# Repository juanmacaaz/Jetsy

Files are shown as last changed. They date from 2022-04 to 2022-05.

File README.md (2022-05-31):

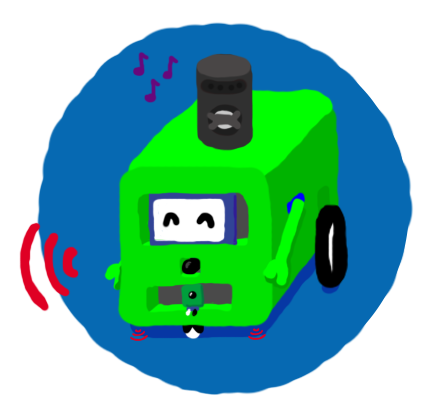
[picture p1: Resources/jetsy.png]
header pic


# Jetsy




Personal assistant robot that interacts with the human being on a physical and emotional level.

# Table of Contents
   * [What is this?](#what-is-this)
   * [Demo](#demo)
   * [Requirements](#requirements)
   * [How to use](#how-to-use)
   * [Components](#components)
   * [Hardware Scheme](#hardware-scheme)
   * [Software Architecture](#software-architecture)
   * [Software Modules](#software-modules)
   * [Eyes](#eyes)
      * [Affirmation](#affirmation)
      * [Loved](#loved)
      * [Suspicious](#suspicious)
      * [Angry](#angry)
      * [Happy](#happy)
      * [Normal](#normal)
      * [Sad](#sad)
   * [Arms](#arms)
   * [Movements](#movements)
      * [Front](#Front)
      * [Left](#Left)
      * [Right](#Right)
      * [Back](#Back)
   * [Proximity Sensors](#proximity-sensors)
   * [Command Voice](#command-voice)
      * [Voice Controller](#voice-controller)
      * [Dance](#dance)
      * [Tell me a joke](#tell-me-a-joke)
      * [Object Classification](#object-classification)
   * [Additional Implementations](#additional-implementations)
   * [Built With](#built-with)
   * [License](#license)
   * [Use-case](#use-case)
   * [Amazing Contribution](#amazing-contribution)
   * [How to contribute](#How-to-contribute)
   * [Citing](#citing)
   * [Support](#support)
   * [Authors](#authors)
   * [Bibliography](#bibliography)

# What is this?
This project seeks to create an autonomous robot completely focused on emotional interaction with the user. It will be carried out by means of a table assistant with already existing typical functionalities, but thanks to artificial intelligence you will be able to interact with it through voice and video and thus enhance robot-human interaction seeking the maximum fluidity possible.

We also believe that the aesthetic design of the robot is very important to be able to transmit emotions to the user, so it will be very well worked.

Another point that we want is that all software has to be open source, from deep learning models to used libraries. You do not need an internet connection to use most of its features.

# Demo
Demo (https://www.youtube.com/watch?v=N_IYzQ1feL4)

# Requirements

For running each sample code:

- [Python 3.9.x](https://www.python.org/)

- [pytorch](https://pytorch.org/)
- [opencv](https://opencv.org/)
- [pipwin](https://pypi.org/project/pipwin/)
- [pyaudio](https://pypi.org/project/PyAudio/)
- [pygame](https://www.pygame.org/)
- [torchaudio](https://pytorch.org/audio/)
- [omegaconf](https://omegaconf.readthedocs.io/)
- [sox](https://pypi.org/project/sox/)
- [noisereduce](https://pypi.org/project/noisereduce/)
- [Levenshtein](https://en.wikipedia.org/wiki/Levenshtein_distance)
- [fuzzywuzzy](https://pypi.org/project/fuzzywuzzy/)

# How to use

1. Clone this repo.

> git clone https://github.com/juanmacaaz/Jetsy

2. Go to the directory where the code is located.

> cd Jesty

3. Install the required libraries.
 
using pip :

> pip install -r Requirements/requirements.txt

4. Execute the following command to run the sample code.

> python3 run.py

5. Add star to this repo if you like it :smiley:. 

# Components
<table align="center" border="0">
<tr>

<td align="center">

[SainSmart Dysplay](https://www.amazon.com/-/es/SainSmart-Display-adaptador-Arduino-2560-Nano/dp/B008FWSG3S)
</td><td align="center">

[Raspberry Pi Camera](https://es.aliexpress.com/item/4001162865845.html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)
</td><td align="center">

[Sg90](https://es.aliexpress.com/item/1005001943420922.html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)
</td><td align="center">

[GA12-N20 DC](https://es.aliexpress.com/item/1005003480074662.html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)
</td></tr>

<tr>
    <td align="center">
        
        
    </td>
    <td align="center">
        
        
    </td>
    <td align="center">
        
        
    </td>
    <td align="center">
        
        
    </td>
</tr>

<tr>

<td align="center">

[infrared barrier module](https://es.aliexpress.com/item/32903218497.html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)
</td><td align="center">

[infrared barrier module](https://es.aliexpress.com/item/1005001621744601.html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)
</td><td align="center">

[L298N](https://www.amazon.es/Neuftech-Puente-conductor-controlador-arduino/dp/B01KBTNHS6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)
</td><td align="center">

[Plastic AA Battery Holder](https://es.aliexpress.com/item/1005001866700713.html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)
</td></tr>

<tr>
    <td align="center">
        
        
    </td>
    <td align="center">
        
        
    </td>
    <td align="center">
        
        
    </td>
    <td align="center">
        
        
    </td>
</tr>

<tr>

<td align="center">

[Arduino Uno](https://es.farnell.com/arduino/k010007/starter-kit-arduino-uno-board/dp/2356913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)
</td><td align="center">

[Power Bank](https://www.amazon.es/Ekrist-26800mAh-Portatil-Powerbank-Cargador/dp/B07TQ43RY2?th=1)
</td><td align="center">

[ALT-37](https://www.carrefour.es/mini-altavoz-innova-wireless-innsoul-alt-37/VC4A-17700772/p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)
</td><td align="center">

[USB Microphone](https://www.amazon.es/Micr%C3%B3fono-Seacue-Omnidireccional-Condensador-Entrevistas/dp/B071171DBP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)
</td></tr>

<tr>
    <td align="center">
        
        
    </td>
    <td align="center">
        
        
    </td>
    <td align="center">
        
        
    </td>
    <td align="center">
        
        
    </td>
</tr>

<tr>

<td align="center">

[Front cover](https://github.com/juanmacaaz/Jetsy/blob/main/HardwareDesign/Models/cuerpo1.stl)
</td><td align="center">

[Back cover](https://github.com/juanmacaaz/Jetsy/blob/main/HardwareDesign/Models/cuerpo2.stl)
</td><td align="center">

[Arms](https://github.com/juanmacaaz/Jetsy/blob/main/HardwareDesign/Models/brazos.stl)
</td><td align="center">

[Battery Cover](https://github.com/juanmacaaz/Jetsy/blob/main/HardwareDesign/Models/tapa.stl)
</td></tr>

<tr>
    <td align="center">
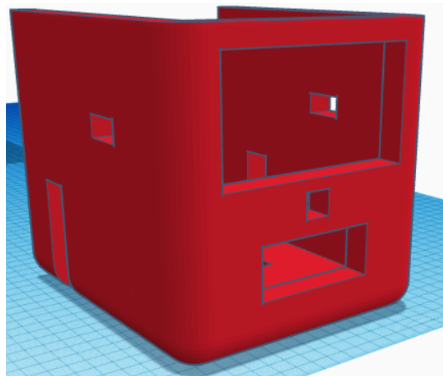
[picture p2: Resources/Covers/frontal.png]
        
        
    </td>
    <td align="center">
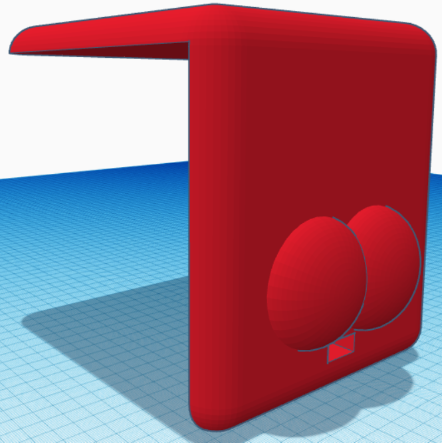
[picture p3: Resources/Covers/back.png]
        
        
    </td>
    <td align="center">
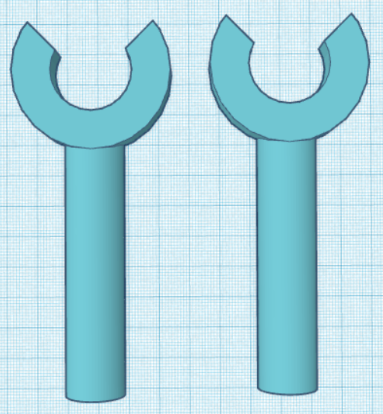
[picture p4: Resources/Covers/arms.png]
        
        
    </td>
    <td align="center">
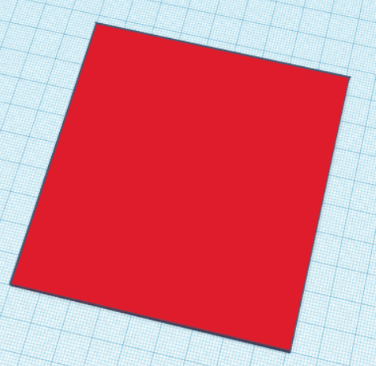
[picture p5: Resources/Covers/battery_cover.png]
        
        
    </td>
</tr>

<tr><td colspan="4">

# Hardware Scheme
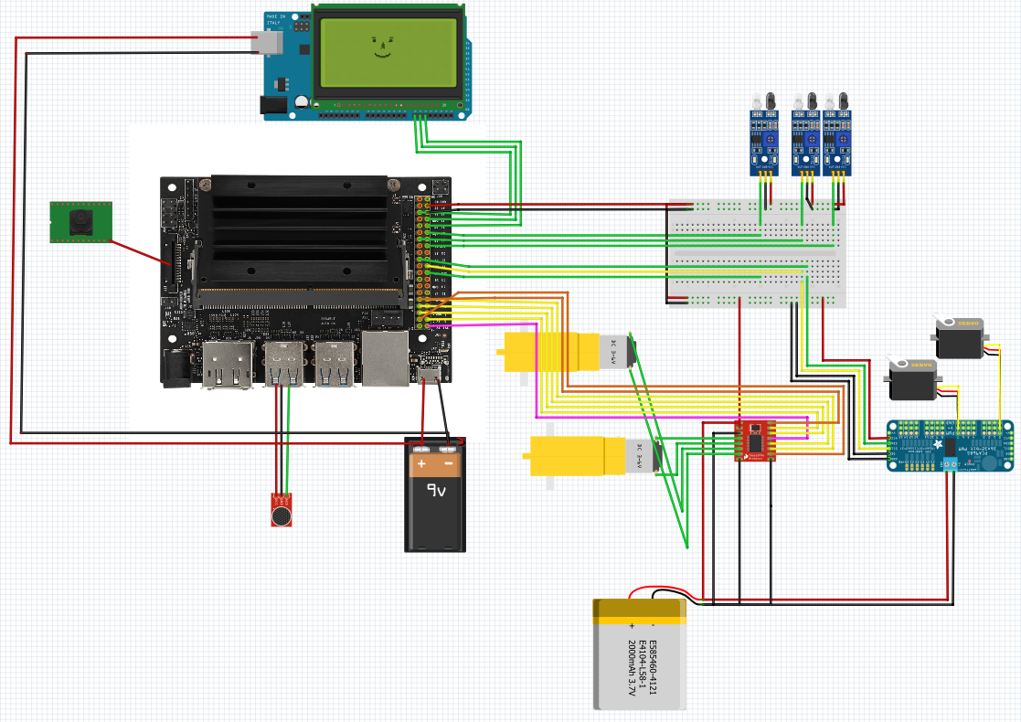
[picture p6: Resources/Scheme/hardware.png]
hardware pic


# Software Architecture
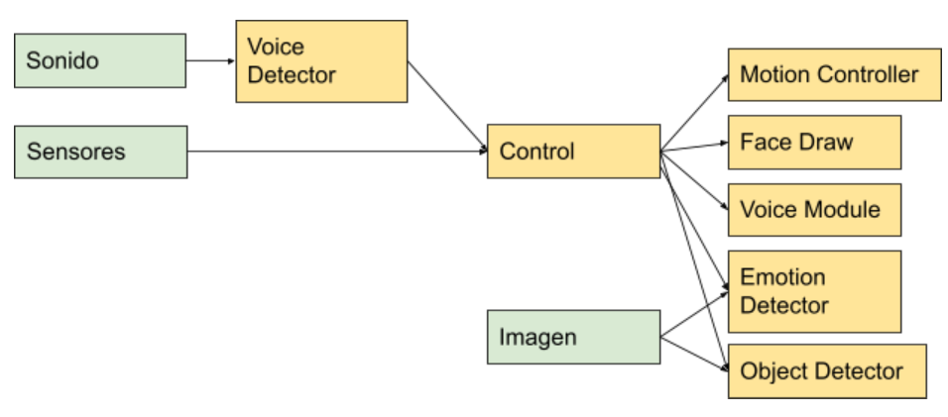
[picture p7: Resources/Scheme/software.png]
software pic


# Software Modules
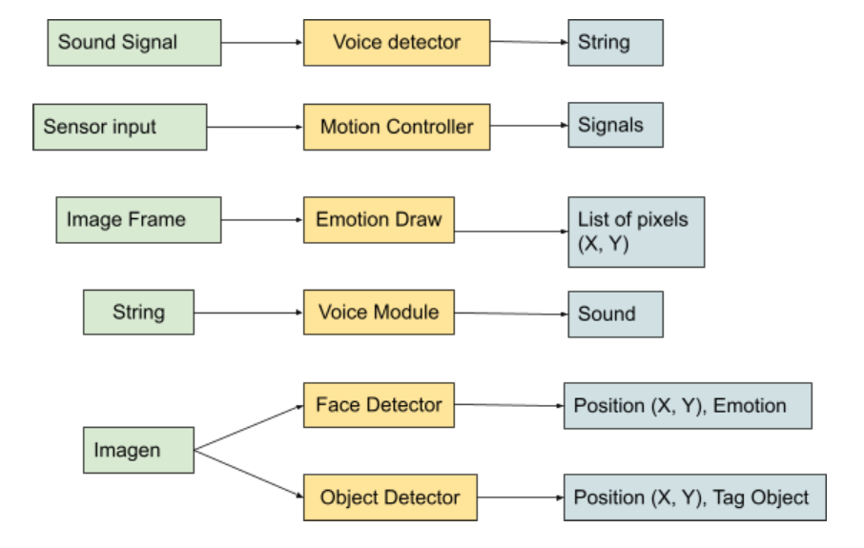
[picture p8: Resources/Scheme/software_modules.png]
software modules pic


# Eyes
## Affirmation
affirmation pic

## Loved
loves pic

## Suspicious
suspicius pic

## Angry
angry pic

## Happy
happy pic

## Normal
normal pic

## Sad
sad pic

# Arms
arm move pic

# Movements
## Front
go pic

## Left
left pic

## Right
right pic

## Back
back pic

# Proximity Sensors
## Frontal
sensor pic

# Command Voice
## Voice Controller
Voice Controller (https://www.youtube.com/watch?v=iem644UcZ8E)

## Dance
Dance (https://www.youtube.com/watch?v=3rkEBKqAFxo)

## Tell me a joke
tell me a joke (https://youtu.be/mcBkq9uVq2E)

## Object Classification
object classification (https://www.youtube.com/watch?v=gnggCI5NF00)

# Additional Implementations
- Where I am
- Emotion Detection
# Built With
- [TinkerCard](https://www.tinkercad.com/) - Model Design Program.
- [Arduino](https://www.arduino.cc/) - IDE used for the development of the servos.
- [VSCode](https://code.visualstudio.com/) - Code editor to program hardware components.
- [Python](https://www.python.org/) - Language used for programming.
- [Adoble Suit](https://www.adobe.com/) - For visual content creation.
# License
This project is under the MIT License - see the [LICENSE](https://github.com/juanmacaaz/Jetsy/blob/main/LICENSE.md) file for details

# Use-Case
If this project helps your robotics project, please let us know with creating an issue.

# Amazing Contribution
- An emotional human-robot interaction never seen before.
- Table assistant 2.0 equipped with artificial intelligence.
- An assistant with next-level computer vision. Leaving current trade assistants behind.
- An easy-to-program framework to add new functionality to the robot.
- All the code is open-source and does not require the internet to work.

# How to contribute
## New estates
In order to create new states you can follow these steps:
1. Adds the initial state of the new functionality in the Default state, this is found in ```state/StateMove.py```.
  
```
  class Default(State):
    next_states = {
        -1: 'Default',
        0: 'Default',
        1: 'InitObject',
        2: 'InitEmotion',
        3: 'InitRepite',
        4: 'InitJoke',
        5: 'InitWhereAmI'
        6: 'Ejemplo1'
    }

    def run(self, kwargs):
        #self.state_machine.global_data['audio'] = None
        audio_state = self.state_machine.global_data['audio']
        kwargs = {}
        self.go_to(self.next_states[audio_state], kwargs)
```
  
2. Create a new voice instruction in ```VoiceDetector/StringMaching.py``` inside list FRASES.
  
```
 FRASES = [
    ("hola detecta objeto", 1),
    ...
    ("hola, esto es un ejemplo", 6)
  ]
```
  
Note: that the second value of the tuple corresponds to the identifier of the new state created in step 1.
  
3. You can now create the different states necessary to carry out the new functionality:
  
```
class Ejemplo1(State):
    def run(self, kwargs):
        kwargs = {}
        kwargs['variable'] = ‘Vengo del estado uno’
        print(f"Inicializando sequencia de test")
        self.go_to("Ejemplo2", kwargs)

class Ejemplo2(State):
    def run(self, kwargs):
        kwargs = {}
        print(f’Mostramos variable {kwargs['variable']}’)
        print(‘Modificamos variable y creamos otra’)
        kwargs['variable']  = ‘He pasado por el estado 2’
        kwargs['variable2'] = ‘He sido creado por el estado 2’
        print(f"Volvemos al estado 1")
        self.go_to("Ejemplo1", kwargs)
 ```
  
**Any contribution is welcome!!**

Contact us via [email](mailto:juanma.caaz@gmail.com).
# Citing
If you use this project's code for your academic work or in industry, we'd love to hear from you as well; feel free to reach out to the developers directly.
# Support 
- [Escola d'Enginyeria - UAB Barcelona](https://www.uab.cat/enginyeria/)
- [UAB Open Labs](https://www.uab.cat/open-labs/)
# Authors
* **Juan Manuel Camara** - [juanmacaaz](https://github.com/juanmacaaz)
* **Miguel del Arco** - [migueldemollet](https://github.com/migueldemollet)
* **Daniel Suarez** - [Danny-8](https://github.com/Danny-8)
* **Christian Ferre** - [christian-ferre](https://github.com/christian-ferre)

# Bibliography
- [Controlar un servo con arduino, Luis Llamas, 2016](https://www.luisllamas.es/controlar-un-servo-con-arduino/)
- [Modulo sensor de llama, Andrés Cortés, 2021](https://acortes.co/proyecto-14-modulo-sensor-de-llama/)
- [Tutorial de uso del modulo l298n, Naylamp Mechatronics, 2017](https://naylampmechatronics.com/blog/11_tutorial-de-uso-del-modulo-l298n.html)
- [CSI Camera, Jetson Hacks Nano, 2019](https://github.com/JetsonHacksNano/CSI-Camera)

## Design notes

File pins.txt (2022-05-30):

dc motors
ENA = 33
ENB = 11
IN1 = 35
IN2 = 37
IN3 = 31
IN4 = 29
----------------------
servos
sda = 3
scl = 5
---------------------
sensor
left = 13
right = 15
frontal = 16
--------------------
pantalla
pin1 = 32
pin2 = 38
pin3 = 40

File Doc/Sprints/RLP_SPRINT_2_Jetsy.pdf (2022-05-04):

RPL - Computer Engineering. UAB (Barcelona) 2020-2021

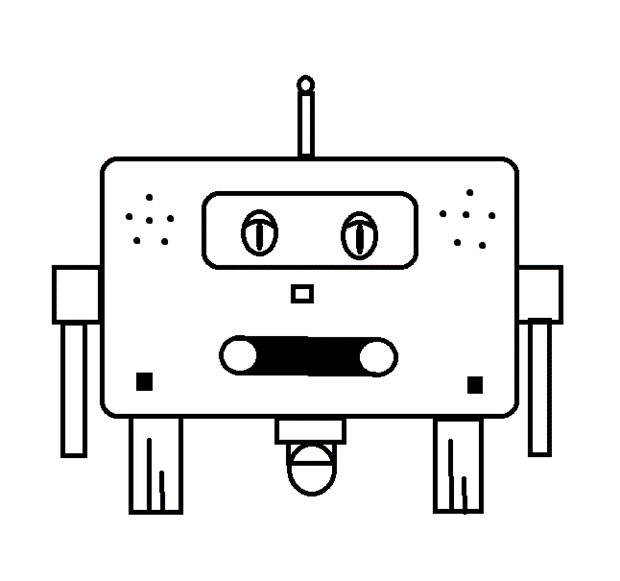
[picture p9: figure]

# JETSY

Robot asistente personal que interactúa con el ser humano a nivel físico y emocional.

PROJECT SPRINT #2.
DATE: 14

th April 2021

Juan Manuel Camara Diaz 1566532 Miguel del Arco Marquez 1566698 Daniel Suárez Valverde 1566103 Christian Ferré Delgado 1565129

JETSY

# Table of Contents

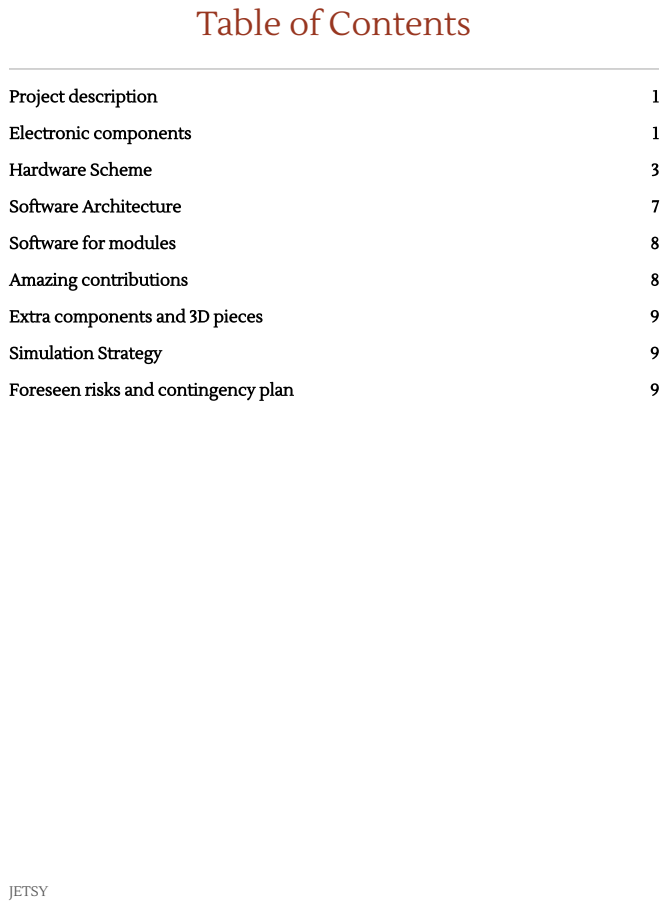
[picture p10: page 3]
Project description; Electronic components; Hardware Scheme; Software Architecture; Software for modules; Amazing contributions; Extra components and 3D pieces; Simulation Strategy; Foreseen risks and contingency plan; JETSY

Sprint #1
Date: 14 April 2021

# JETSY

Robot asistente personal que interactúa con el ser humano a nivel físico y emocional.

Project description
Este proyecto busca crear un robot autónomo completamente enfocado a una interacción emocional con el usuario. Se llevará a cabo mediante un asistente de mesa con funcionalidades típicas ya existentes pero gracias a la inteligencia artificial podrá interactuar con él mediante la voz y video y así potenciar la interacción robot-humano buscando la máxima fluidez posible.

También creemos que el diseño estético del robot es muy importante para poder transmitir emociones al usuario por lo que estará muy trabajado.

Otro punto que queremos es que todo el software tenga que ser open source, desde los modelos de deep learning hasta las librerías usadas. No necesita conexión a internet para poder utilizar la mayoría de sus funcionalidades.

Electronic components
This is the list of the used components:
- Micro servo miniatura SG90 x 3
- Kit motores Dagu 140RPM (2 unidades)
- Controlador de motores TB6612FNG
- Amplificador de audio I2S MAX98357A (3W)
- Batería Lipo 3500mAh 2S 25C, 7.4V
JETSY | 1

- Arducam 5MP 1080p OV5647 RASPBERRY PI
- Altavoz con caja - 3W
- tft_320qvt_9341
- Micrófono electret preamplificado
- Power Bank 5000 MAh, 1x USB-A
- Raspberry Pi 3 Modelo A+ (Jetson Nano)
- INMSDH32G-100V10
- SENSOR INFRARROJO DE LLAMA x 2
- Controlador de Servos PCA9685
JETSY | 2

Hardware Scheme
Diagrama del Hardware

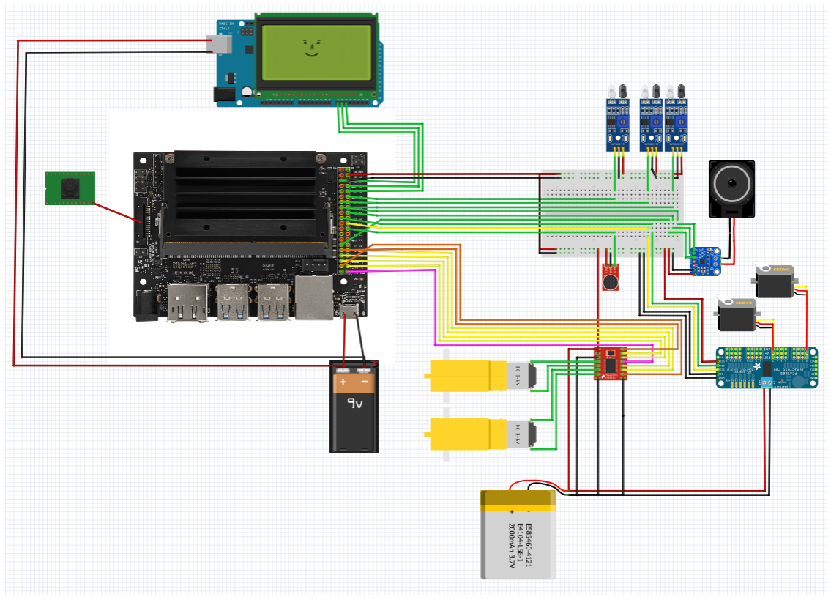
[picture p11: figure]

- Controlador de Servos PCA9685
- GND -> GND(38)
- OE -> GND(38)
- SCL -> PinOut(10)
- SDA -> PinOut(32)
- VCC -> 5V (39)
JETSY | 3

- Micro servo miniatura SG90 x2
- VCC -> V+(0,7) (Controlador de Servos PCA9685)
- GND -> GND(0,7) (Controlador de Servos PCA9685)
- Pulse -> PWM (0,7) (Controlador de Servos PCA9685)
- Kit motores Dagu 140RPM x2
- Pin1 -> A01/B02 (Controlador de motores TB6612FNG)
- Pin1 -> A02/B01 (Controlador de motores TB6612FNG)
- Controlador de motores TB6612FNG
- VM -> + (Batería Lipo 3500mAh 2S 25C, 7.4V)
- VCC -> 5V (39)
- GND -> - (Batería Lipo 3500mAh 2S 25C, 7.4V)
- PWMA -> PinOut(16)
- AIN2 -> PinOut(22)
- AIN1 -> PinOut(18)
- STBY -> PinOut(21)
- BIN1 -> PinOut(17)
- BIN2 -> PinOut(25)
- PWMB -> PinOut(19)
- Amplificador de audio I2S MAX98357A (3W)
- VIN -> 5V (39)
JETSY | 4

- GND -> GND(38)
- DIN -> PinOut(15)
- BCLK -> PinOut(28)
- LRC -> PinOut(8)
- Batería Lipo 3500mAh 2S 25C, 7.4V
- Arducam 5MP 1080p OV5647 RASPBERRY PI
- Conexion camara Jetson
- Altavoz con caja - 3W
- + -> + (Amplificador de audio I2S MAX98357A (3W))
- - -> - (Amplificador de audio I2S MAX98357A (3W))
- tft_320qvt_9341
- Conectada directamente al arduino con el adaptador
- Micrófono electret preamplificado
- VCC -> 5V (39)
- GND -> GND(38)
- AUD -> PinOut(29)
- Power Bank 5000 MAh, 1x USB-A
- Micro USB Jetson
- Raspberry Pi 3 Modelo A+ (Jetson Nano)
- INMSDH32G-100V10
JETSY | 5

- SD socket
- SENSOR INFRARROJO DE LLAMA x3
- VCC -> 5V (39)
- GND -> GND(38)
- OUT -> PinOut(7, 33, 35)
JETSY | 6

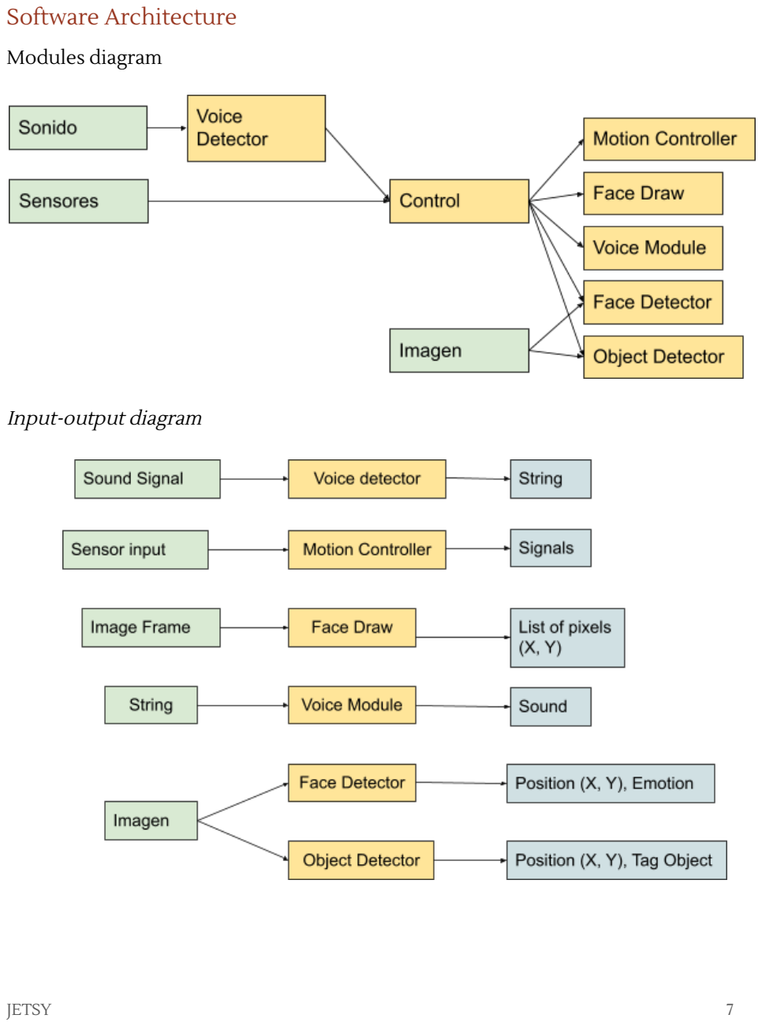
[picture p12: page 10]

Software Architecture
Modules diagram

Input-output diagram

JETSY | 7

Software modules
Para los diferentes módulos vamos a usar el siguiente software:

Voice Detector: Utiliza un modelo pre-entrenado de reconocimiento de voz, los comandos de voz serán en inglés. El modelo es: https://github.com/snakers4/silero-models

Monitor Controller: Máquina de estados del robot y quien comunica todos los

Face Draw: Es una máquina de estado de animaciones implementada en el arduino mega. Los estados serán controlados por los pines de input. Para poder almacenar las animaciones de los ojos hemos tenido que crear un script para poder comprimirlas. La compresión se basa en solo almacenar aquellos píxeles que son modificados respecto al frame anterior. Gracias a esto conseguimos comprimir hasta 800 veces de promedio las animaciones. También conseguimos que la animación se vea super fluida aun teniendo una pantalla con una tasa de refresco muy limitada.

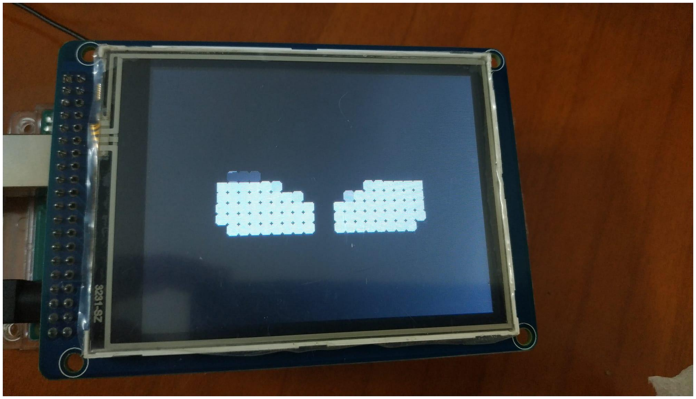
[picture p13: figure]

Las animaciones comprimidas tienen el siguiente formato (Cada campo es un byte):

[#Frames] [#Cambios frame 0] [#Cambios frame 1] . . . [Cambios frame 0] . . .

Voice Module: Función que recibe un string como input y envía al altavoz la orden para que reproduzca el contenido del string.

La implementación de este módulo ha sido mediante la librería “pyttsx3”. Hemos elegido esta librería ya que es offline y muy eficiente.

JETSY | 8

Face Detector: Función que recibe como input una imagen, ésta es preprocesada para lograr simplificar la información lo máximo posible y, a través de un modelo clasificador devuelve la etiqueta de la emoción que representa la cara.

Utilizará el siguiente modelo de deep learning para detectar la emoción https://github.com/serengil/deepface

Object Detector: Modelo de deep learning encargado de detectar todo tipo de objetos. Es el siguiente: https://pjreddie.com/darknet/yolo/

Amazing contributions
Una interacción humano-robot emocional nunca vista.

Asistente de mesa 2.0 dotado de inteligencia artificial.

Un asistente con una visión por computador al siguiente nivel. Dejando atrás a los asistentes comerciales actuales.

JETSY | 9

Extra components and 3D pieces
- Cuerpo del robot (carcasas)
- Frontal

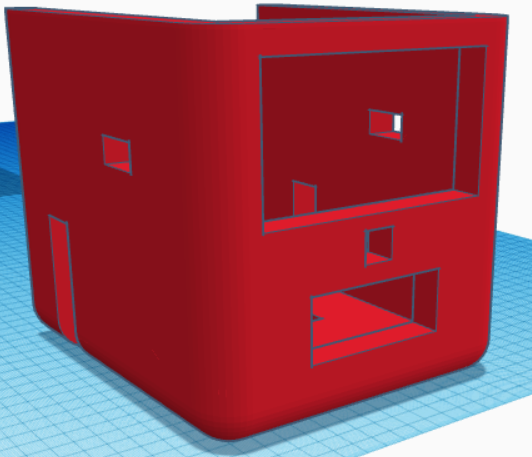
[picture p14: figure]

- Trasero

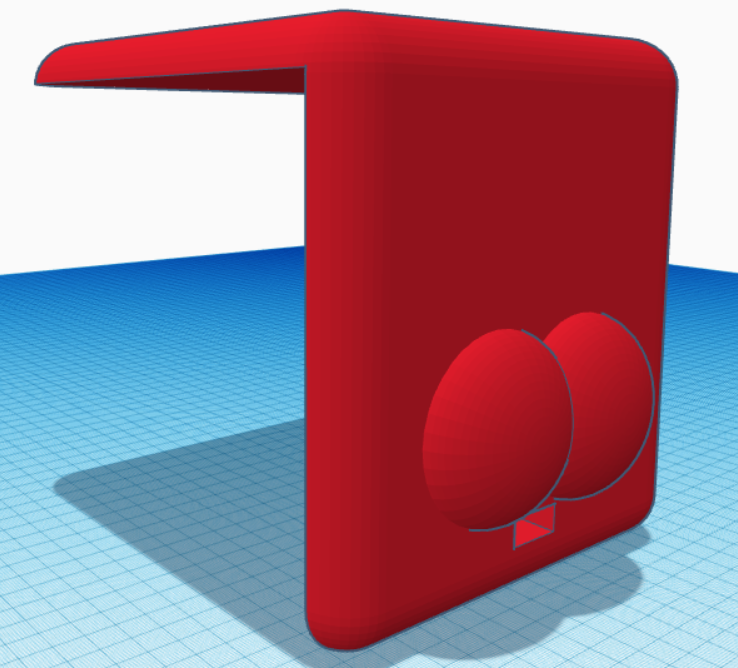
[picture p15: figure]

JETSY | 10

- Brazo x2

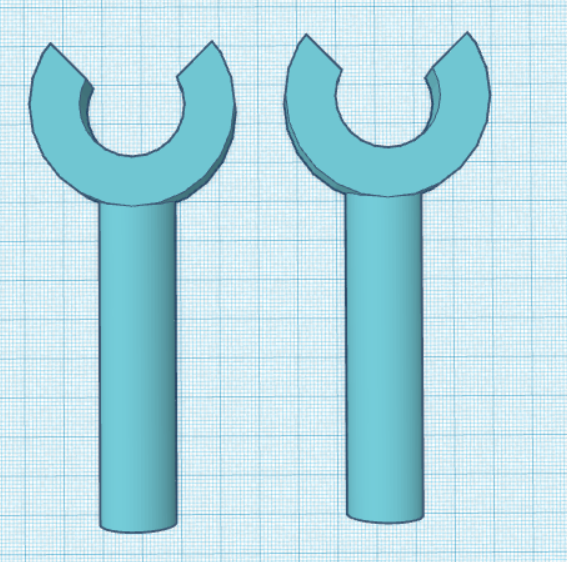
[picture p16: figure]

- Tapa de pilas

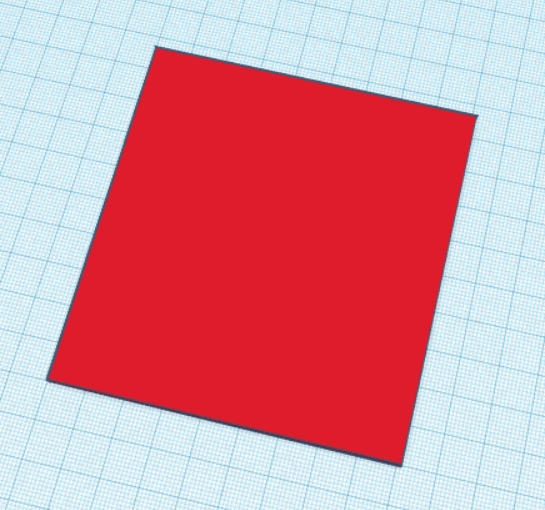
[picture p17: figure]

JETSY | 11

Simulation Strategy
Para llevar a cabo el robot vamos a crear algunos simuladores mientras se realiza la implementación hardware software.

Para simular una pantalla LCD crearemos un simulador con la librería: PyGame

Al obtener las piezas no hemos optado por simular nada hardware. Todo el software para ser testeado será con un ordenador con Ubuntu 20.04, por lo que no necesitaremos ningún tipo de simulador.

Foreseen risks and contingency plan

Risk# | Description | Probability | Impact | Contingency plan
1 | Fallo de Bateria | Low | Low | No usar baterias
2 Bajo rendimiento | de CPU/GPU | Low | Low | Reducir el número de módulos de Deep Learning.
3 Máquina de | estados compleja | Medium | Low | Reducir las funcionalidades del robot
4 Mal | reconocimiento de voz | Low | Medium | Ajustar algunas palabras clave
5 Grandes | interferencias de audio | Low | Medium | Reducir la calidad del sonido para evitar las interferencias o usar una api externa.
6 No hacer un | proyecto open-source | Medium | Low | Usar código y APIs no open-source
7 Que el robot no | se pueda estabilizar bien con las ruedas | Low | Medium | Distribución correcta del peso
JETSY | 12

### 8 Falta de espacio

dentro del robot

Low | Medium | Hacer un buen diseño 3D de las piezas o hacerlo manual
JETSY | 13

# References

This project has been inspired by the following Internet projects:

- https://living.ai/emo/
- https://developer.amazon.com/es-ES/alexa
- https://www.digitaldreamlabs.com/pages/cozmo

Other links

- https://www.youtube.com/watch?v=8QD6HqL9Qc0&t=7s
- https://pjreddie.com/darknet/yolo/
- https://github.com/snakers4/silero-models
- https://github.com/serengil/deepface
JETSY | 14

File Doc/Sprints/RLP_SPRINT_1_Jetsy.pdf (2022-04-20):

RPL - Computer Engineering. UAB (Barcelona) 2020-2021


# JETSY

Robot asistente personal que interactúa con el ser humano a nivel físico y emocional.

PROJECT SPRINT #0.
DATE: 14

th April 2021

Juan Manuel Camara Diaz 1566532 Miguel del Arco Marquez 1566698 Daniel Suárez Valverde 1566103 Christian Ferré Delgado 1565129

JETSY

# Table of Contents

Project description; Electronic components; Hardware Scheme; Software Architecture; Software for modules; Amazing contributions; Extra components and 3D pieces; Simulation Strategy; Foreseen risks and contingency plan; JETSY

Sprint #1
Date: 14 April 2021

# JETSY

Robot asistente personal que interactúa con el ser humano a nivel físico y emocional.

Project description
Este proyecto busca crear un robot autónomo completamente enfocado a una interacción emocional con el usuario. Se llevará a cabo mediante un asistente de mesa con funcionalidades típicas ya existentes pero gracias a la inteligencia artificial podrá interactuar con él mediante la voz y video y así potenciar la interacción robot-humano buscando la máxima fluidez posible.

También creemos que el diseño estético del robot es muy importante para poder transmitir emociones al usuario por lo que estará muy trabajado.

Otro punto que queremos es que todo el software tenga que ser open source, desde los modelos de deep learning hasta las librerías usadas. No necesita conexión a internet para poder utilizar la mayoría de sus funcionalidades.

Electronic components
This is the list of the used components:
- Sensor de distancia por ultrasonidos
- Micro servo miniatura SG90 x 3
- Kit motores Dagu 140RPM (2 unidades)
- Controlador de motores TB6612FNG
- Amplificador de audio I2S MAX98357A (3W)
JETSY | 1

- Batería Lipo 3500mAh 2S 25C, 7.4V
- Arducam 5MP 1080p OV5647 RASPBERRY PI
- Altavoz con caja - 3W
- tft_320qvt_9341
- Micrófono electret preamplificado
- Power Bank 5000 MAh, 1x USB-A
- Raspberry Pi 3 Modelo A+ (Jetson Nano)
- INMSDH32G-100V10
- SENSOR INFRARROJO DE LLAMA x 2
JETSY | 2

Hardware Scheme
Diagrama del Hardware

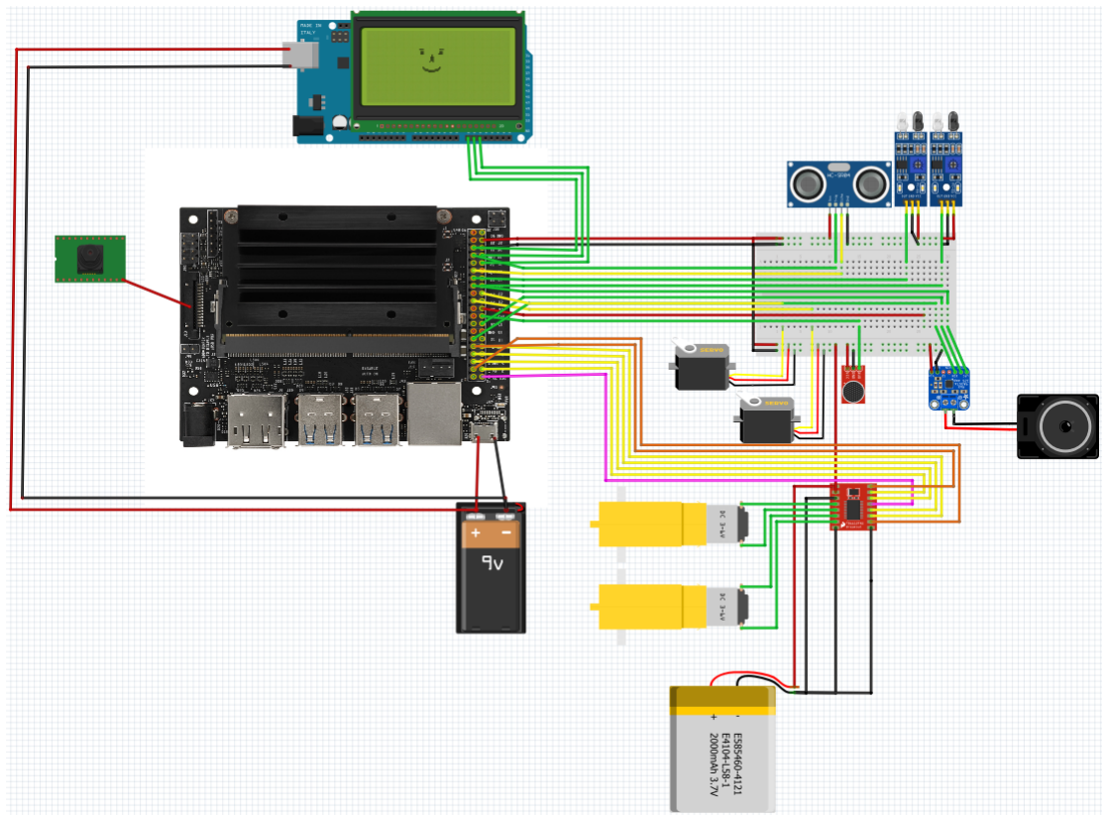
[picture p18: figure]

- Sensor de distancia por ultrasonidos
- VCC -> 5V(39)
- GND -> GND(38)
- Trig -> PinOut(4)
- Echo -> PinOut(6)
JETSY | 3

- Micro servo miniatura SG90
- VCC -> 5V (39)
- GND -> GND(38)
- Pulse -> PinOut(10)
- Micro servo miniatura SG90
- VCC -> 5V (39)
- GND -> GND(38)
- Pulse -> PinOut(32)
- Kit motores Dagu 140RPM
- Pin1 -> A01 (Controlador de motores TB6612FNG)
- Pin1 -> A02 (Controlador de motores TB6612FNG)
- Kit motores Dagu 140RPM
- Pin1 -> B02 (Controlador de motores TB6612FNG)
- Pin1 -> B01 (Controlador de motores TB6612FNG)
- Controlador de motores TB6612FNG
- VM -> + (Batería Lipo 3500mAh 2S 25C, 7.4V)
- VCC -> 5V (39)
- GND -> - (Batería Lipo 3500mAh 2S 25C, 7.4V)
- PWMA -> PinOut(16)
- AIN2 -> PinOut(22)
JETSY | 4

- AIN1 -> PinOut(18)
- STBY -> PinOut(21)
- BIN1 -> PinOut(17)
- BIN2 -> PinOut(25)
- PWMB -> PinOut(19)
- Amplificador de audio I2S MAX98357A (3W)
- VIN -> 5V (39)
- GND -> GND(38)
- DIN -> PinOut(15)
- BCLK -> PinOut(28)
- LRC -> PinOut(8)
- Batería Lipo 3500mAh 2S 25C, 7.4V
- Arducam 5MP 1080p OV5647 RASPBERRY PI
- Conexion camara Jetson
- Altavoz con caja - 3W
- + -> + (Amplificador de audio I2S MAX98357A (3W))
- - -> - (Amplificador de audio I2S MAX98357A (3W))
- tft_320qvt_9341
- Conectada directamente al arduino con el adaptador
- Micrófono electret preamplificado
JETSY | 5

- VCC -> 5V (39)
- GND -> GND(38)
- AUD -> PinOut(29)
- Power Bank 5000 MAh, 1x USB-A
- Micro USB Jetson
- Raspberry Pi 3 Modelo A+ (Jetson Nano)
- INMSDH32G-100V10
- SD socket
- SENSOR INFRARROJO DE LLAMA
- VCC -> 5V (39)
- GND -> GND(38)
- OUT -> PinOut(7)
- SENSOR INFRARROJO DE LLAMA
- VCC -> 5V (39)
- GND -> GND(38)
- OUT -> PinOut(33)
JETSY | 6

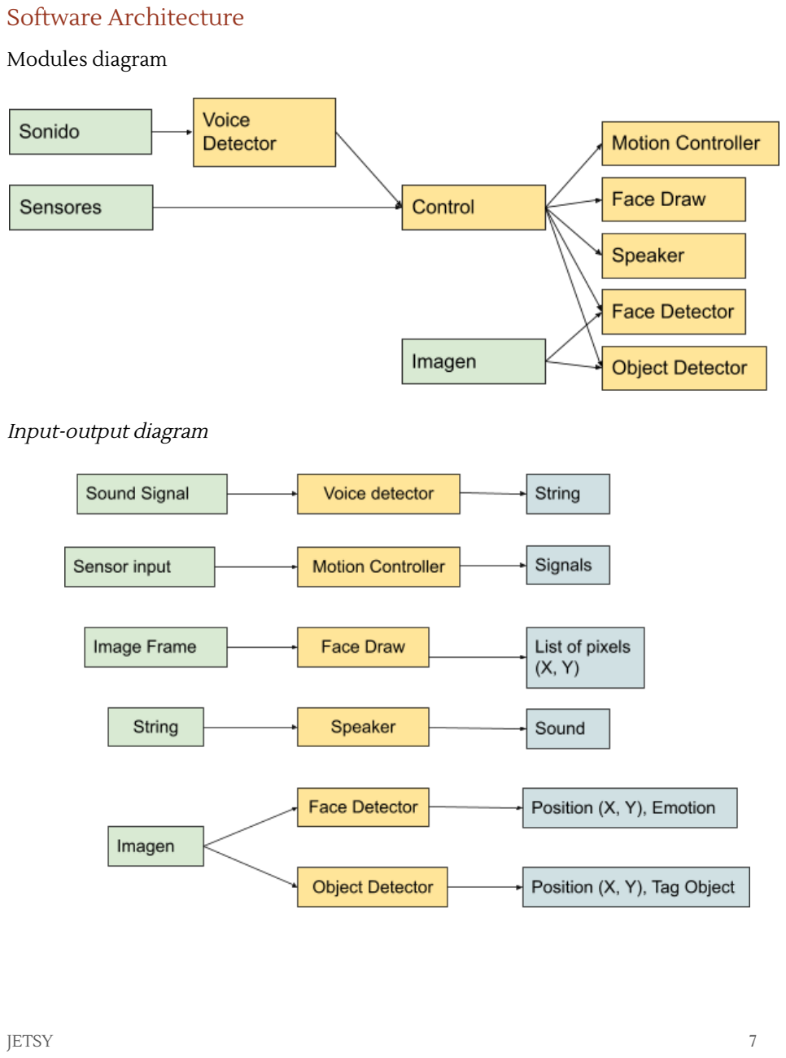
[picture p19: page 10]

Software Architecture
Modules diagram

Input-output diagram

JETSY | 7

Software for modules
Para los diferentes módulos vamos a usar el siguiente software:

Voice Detector: Utiliza un modelo pre-entrenado de reconocimiento de voz, los comandos de voz serán en inglés. El modelo es: https://github.com/snakers4/silero-models

Monitor Controller: Máquina de estados del robot y quien comunica todos los

Face Draw: Es una máquina de estado de animaciones implementada en el arduino mega. Los estados serán controlados por los pines de input.

Speaker: Función que recibe un string como input y envía al altavoz la orden para que reproduzca el contenido del string.

Face Detector: Función que recibe como input una imagen, ésta es preprocesada para lograr simplificar la información lo máximo posible y, a través de un modelo clasificador devuelve la etiqueta de la emoción que representa la cara.

Utilizará el siguiente modelo de deep learning para detectar la emoción https://github.com/serengil/deepface

Object Detector: Modelo de deep learning encargado de detectar todo tipo de objetos. Es el siguiente: https://pjreddie.com/darknet/yolo/

Amazing contributions
Una interacción humano-robot emocional nunca vista.

Asistente de mesa 2.0 dotado de inteligencia artificial.

Un asistente con una visión por computador al siguiente nivel. Dejando atrás a los asistentes comerciales actuales.

JETSY | 8

Extra components and 3D pieces
- Cuerpo del robot (carcasas)
- Frontal


- Trasero


JETSY | 9

- Brazo x2


- Tapa de pilas


JETSY | 10

Simulation Strategy
Para llevar a cabo el robot vamos a crear algunos simuladores mientras se realiza la implementación hardware software.

Para simular una pantalla LCD crearemos un simulador con la librería: PyGame

Al obtener las piezas no hemos optado por simular nada hardware. Todo el software para ser testeado será con un ordenador con Ubuntu 20.04, por lo que no necesitaremos ningún tipo de simulador.

Foreseen risks and contingency plan

Risk# | Description | Probability | Impact | Contingency plan
1 | Fallo de Bateria | Low | Low | No usar baterias
2 Bajo rendimiento | de CPU/GPU | Low | Low | Reducir el número de módulos de Deep Learning.
3 Máquina de | estados compleja | Medium | Low | Reducir las funcionalidades del robot
4 Mal | reconocimiento de voz | Low | Medium | Ajustar algunas palabras clave
5 Grandes | interferencias de audio | Low | Medium | Reducir la calidad del sonido para evitar las interferencias o usar una api externa.
6 No hacer un | proyecto open-source | Medium | Low | Usar código y APIs no open-source
7 Que el robot no | se pueda estabilizar bien con las ruedas | Low | Medium | Distribución correcta del peso
JETSY | 11

### 8 Falta de espacio

dentro del robot

Low | Medium | Hacer un buen diseño 3D de las piezas o hacerlo manual
JETSY | 12

# References

This project has been inspired by the following Internet projects:

- https://living.ai/emo/
- https://developer.amazon.com/es-ES/alexa
- https://www.digitaldreamlabs.com/pages/cozmo

Other links

- https://www.youtube.com/watch?v=8QD6HqL9Qc0&t=7s
- https://pjreddie.com/darknet/yolo/
- https://github.com/snakers4/silero-models
- https://github.com/serengil/deepface
JETSY | 13

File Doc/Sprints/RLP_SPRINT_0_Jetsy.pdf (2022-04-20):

RPL - Computer Engineering. UAB (Barcelona) 2020-2021


# JETSY

Robot asistente personal que interactúa con el ser humano a nivel físico y emocional.

PROJECT SPRINT #0.
DATE: 14

th April 2021

Juan Manuel Camara Diaz 1566532 Miguel del Arco Marquez 1566698 Daniel Suárez Valverde 1566103 Christian Ferré Delgado 1565129

JETSY

# Table of Contents

Project description | 1
Electronic components | 1
Scheme | 1
Extra components and 3D pieces | 1
Foreseen risks and contingency plan | 2

JETSY

Sprint #0
Date: 14 April 2021

# JETSY

Robot asistente personal que interactúa con el ser humano a nivel físico y emocional.

Project description
Este proyecto busca crear un robot autónomo completamente enfocado a una interacción emocional con el usuario. Se llevará a cabo mediante un asistente de mesa con funcionalidades típicas ya existentes pero gracias a la inteligencia artificial podrá interactuar con él mediante la voz y video y así potenciar la interacción robot-humano buscando la máxima fluidez posible.

También creemos que el diseño estético del robot es muy importante para poder transmitir emociones al usuario por lo que estará muy trabajado.

Otro punto que queremos es que todo el software tenga que ser open source, desde los modelos de deep learning hasta las librerías usadas.

Electronic components
This is the list of the used components:
- Sensor de distancia por ultrasonidos
- Micro servo miniatura SG90 x 3
- Kit motores Dagu 140RPM (2 unidades)
- Controlador de motores TB6612FNG
- Amplificador de audio I2S MAX98357A (3W)
- Batería Lipo 3500mAh 2S 25C, 7.4V
JETSY | 1

- Arducam 5MP 1080p OV5647 RASPBERRY PI
- Altavoz con caja - 3W
- PANTALLA 1.8" LCD/TFT
- Micrófono electret preamplificado
- Power Bank 5000 MAh, 1x USB-A
- Raspberry Pi 3 Modelo A+ (Jetson Nano)
- INMSDH32G-100V10
- SENSOR INFRARROJO DE LLAMA x 2
JETSY | 2

Hardware Scheme
Diagrama del Hardware

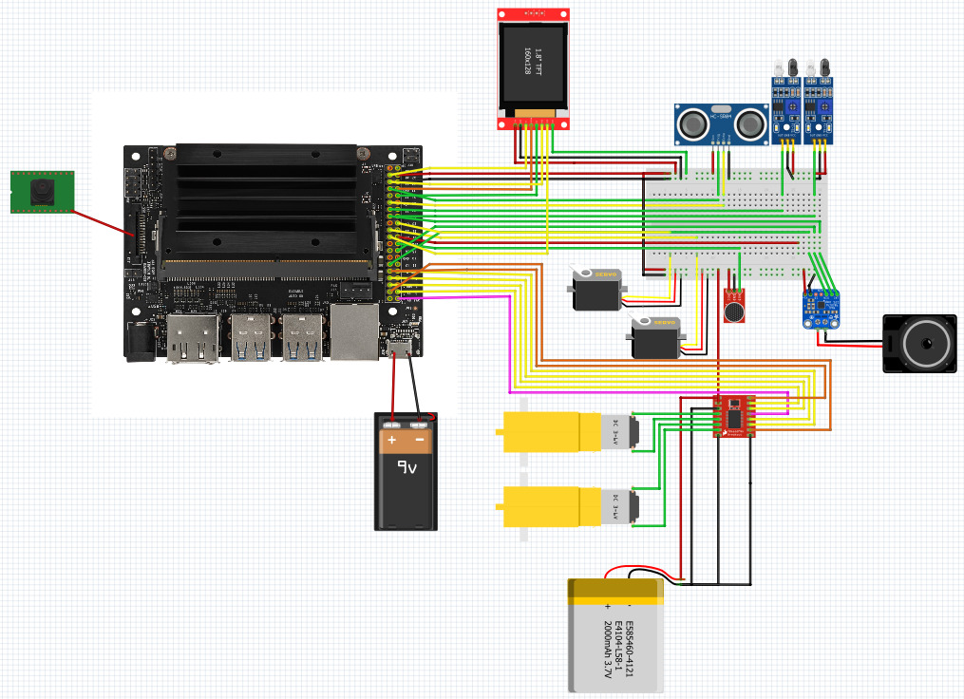
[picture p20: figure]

- Sensor de distancia por ultrasonidos
- VCC -> 5V(39)
- GND -> GND(38)
- Trig -> PinOut(4)
- Echo -> PinOut(6)
JETSY | 3

- Micro servo miniatura SG90
- VCC -> 5V (39)
- GND -> GND(38)
- Pulse -> PinOut(10)
- Micro servo miniatura SG90
- VCC -> 5V (39)
- GND -> GND(38)
- Pulse -> PinOut(32)
- Kit motores Dagu 140RPM
- Pin1 -> A01 (Controlador de motores TB6612FNG)
- Pin1 -> A02 (Controlador de motores TB6612FNG)
- Kit motores Dagu 140RPM
- Pin1 -> B02 (Controlador de motores TB6612FNG)
- Pin1 -> B01 (Controlador de motores TB6612FNG)
- Controlador de motores TB6612FNG
- VM -> + (Batería Lipo 3500mAh 2S 25C, 7.4V)
- VCC -> 5V (39)
- GND -> - (Batería Lipo 3500mAh 2S 25C, 7.4V)
- PWMA -> PinOut(16)
- AIN2 -> PinOut(22)
JETSY | 4

- AIN1 -> PinOut(18)
- STBY -> PinOut(21)
- BIN1 -> PinOut(17)
- BIN2 -> PinOut(25)
- PWMB -> PinOut(19)
- Amplificador de audio I2S MAX98357A (3W)
- VIN -> 5V (39)
- GND -> GND(38)
- DIN -> PinOut(15)
- BCLK -> PinOut(28)
- LRC -> PinOut(8)
- Batería Lipo 3500mAh 2S 25C, 7.4V
- Arducam 5MP 1080p OV5647 RASPBERRY PI
- Conexion camara Jetson
- Altavoz con caja - 3W
- + -> + (Amplificador de audio I2S MAX98357A (3W))
- - -> - (Amplificador de audio I2S MAX98357A (3W))
- PANTALLA 1.8" LCD/TFT
- VCC -> 5V(39)
- GND -> GND(38)
JETSY | 5

- CS -> PinOut(2)
- RESET -> PinOut(37)
- A0 -> PinOut(36)
- SDA -> PinOut(3)
- SCK -> PinOut(11)
- LED -> 5V (39)
- Micrófono electret preamplificado
- VCC -> 5V (39)
- GND -> GND(38)
- AUD -> PinOut(29)
- Power Bank 5000 MAh, 1x USB-A
- Micro USB Jetson
- Raspberry Pi 3 Modelo A+ (Jetson Nano)
- INMSDH32G-100V10
- SD socket
- SENSOR INFRARROJO DE LLAMA
- VCC -> 5V (39)
- GND -> GND(38)
- OUT -> PinOut(7)
- SENSOR INFRARROJO DE LLAMA
JETSY | 6

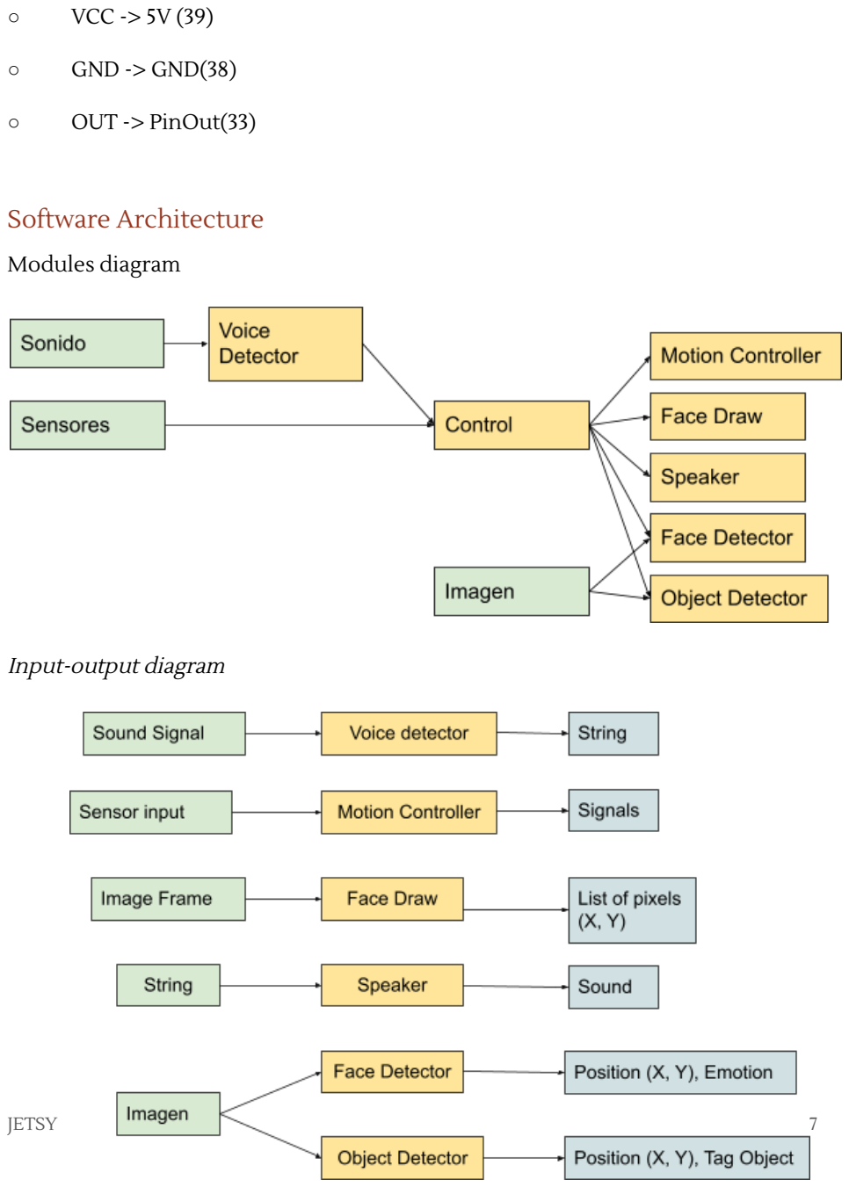
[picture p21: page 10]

- VCC -> 5V (39)
- GND -> GND(38)
- OUT -> PinOut(33)

Software Architecture
Modules diagram

Input-output diagram

JETSY | 7

Amazing contributions
Una interacción humano-robot emocional nunca vista.

Asistente de mesa 2.0

Extra components and 3D pieces
- Cuerpo del robot (carcasas)
- Rueda x2
- Brazo x2
- Rueda loca x1
- Tapa enchufe x1

Simulation Strategy
Para llevar a cabo el robot vamos a crear algunos simuladores mientras se reliza la implmentacion hardware sofrware.

Para simular una pantalla LCD crearemos un simulador.

PyGame

FaceDraw

JETSY | 8

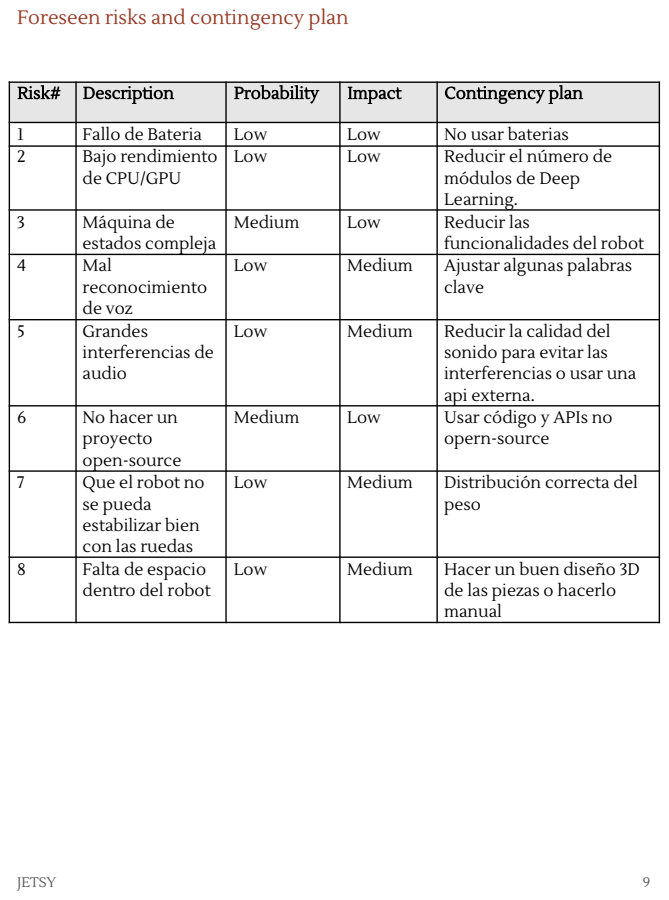
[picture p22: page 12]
JETSY

Foreseen risks and contingency plan

Risk# | Description | Probability | Impact | Contingency plan

1 | Fallo de Bateria | Low | Low | No usar baterias
2 Bajo rendimiento | de CPU/GPU | Low | Low | Reducir el número de módulos de Deep Learning.

3 Máquina de | estados compleja | Medium | Low | Reducir las funcionalidades del robot

4 Mal | reconocimiento de voz | Low | Medium | Ajustar algunas palabras clave

5 Grandes | interferencias de audio | Low | Medium | Reducir la calidad del sonido para evitar las interferencias o usar una api externa.

6 No hacer un | proyecto open-source | Medium | Low | Usar código y APIs no opern-source

7 Que el robot no | se pueda estabilizar bien con las ruedas | Low | Medium | Distribución correcta del peso

8 Falta de espacio | dentro del robot | Low | Medium | Hacer un buen diseño 3D de las piezas o hacerlo manual

# References

This project has been inspired by the following Internet projects:

- https://living.ai/emo/
- https://developer.amazon.com/es-ES/alexa
- https://www.digitaldreamlabs.com/pages/cozmo

Other links

- https://www.youtube.com/watch?v=8QD6HqL9Qc0&t=7s
- https://pjreddie.com/darknet/yolo/
- https://github.com/snakers4/silero-models
JETSY | 10

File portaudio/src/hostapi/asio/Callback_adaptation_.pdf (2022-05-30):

GRAME - Computer Music Research Lab.

### Technical Note - 01-11-07

# Callback adaptation techniques

Stéphane Letz
November 2001
Grame - Computer Music Research Laboratory 9, rue du Garet BP 1185 69202 FR - LYON Cedex 01 letz@grame.fr

Abstract

This document describes a callback adaptation technique developed for the PortAudio port on ASIO. This method handle buffers of different sizes and guarantee lowest latency added by buffer size adaptation.

### 1 Introduction

The callback adaptation problem was encountered whilst doing a port of the PortAudio API on ASIO API. PortAudio is a cross-platform library that provides streaming audio input and output, ASIO is a Macintosh and Windows API that provides streaming audio input and output. Both API are callback based, but may use audio buffers of different size. This document presents an algorithm developed to allow adaptation between the 2 callback systems.

### 2 Adapting callbacks

The system we are considering is driven by an audio native callback (the “host” callback) usually called by the hardware interrupt. The host audio callback has the following prototype :

hostCallback (void* inputBuffer, void* ouputBuffer, int frameNumber, void* userData);

Upon return of the callback, the application has read all input data and provided all output data. InputBuffer and OutputBuffer have the same number or frames M.

The internal callback ( the “user” callback) is implemented by the application and has the following prototype :

userCallback (void* inputBuffer, void* ouputBuffer, int frameNumber, void* userData);

where InputBuffer and OutputBuffer have the same number or frames N.

The user callback will be provided by the application and one need to develop the host (adaptation) callback to be given to the host audio engine. So we have two different callback and in general two different buffer sizes M and N. The running cycle is the following :

M

N | N
N | N

M

host to user buffer

user to host buffer

user callback | host (adaptation) callback

- the hardware fills the host input buffer of size M
- the hostCallback is called
- the host input buffer of size M is transfered to the user input buffer of size N
- the userCallback must be called to produce a user ouput buffer of size N
- the user ouput buffer of size N is transfered into the host ouput bufffer of size M
- the hardware uses the host ouput buffer of size M

Because M and N are in general different, an adpatation system must be developed. Some remaining frames will have to be kept during one cycle to be used during the next cycle. The number of user callback calls in each cycle will not be always the same.

The following constraints must be respected :

- at each host callback a full M frames input buffer is received, this buffer must be completely used, a full M frames ouput buffer must be produced.
- the user callback must always be called with a full N frames input buffer and will produce a N frames ouput buffer.
- latency has to be minimized in a full-duplex case.

### 3 Buffer size adapdation techniques

To be able to adapt the two callbacks, different cases have to be considered :

### 3.1 Case 1 : host buffer size multiple of user buffer size

Input host buffer | M

Input user buffer

Output user buffer

Output host buffer

N | NM

M

N | NM

Nothing difficult here, at each host callback, an M size host buffer is received, because M is a multiple of N, M/N user callback can be called producing a complete M size host output buffer.

### 3.2 Case 2 : host buffer size divisor of user buffer size

N

M | M

M

N

N

Input host buffer | M | M

Input user buffer

Output user buffer

Output host buffer

In the previous simple example where N = 2M, we have the following : at the first host callback, an M size host buffer is received, the user callback can not be called so the host input buffer content is kept. A null host output buffer is produced. At the next host callback, the user callback can be called, producing an M size ouput buffer. An host ouput buffer can be produced consuming M = N/2 frames, and so on. The ouput stream has been globally delayed by a complete M size buffer. The way of doing can be generalized for case where N= n*M.

### 3.3 Case 3 : host buffer size superior of user buffer size

N

M

M

N

Input host buffer

Input user buffer

Output user buffer

Output host buffer

This a more complex case when a more sophisticated buffer size adaptation system must be found. At the first host callback, a host buffer of size M is received. Because M > N, the user callback can be called consuming N frames and producing an output user buffer of N frames. But because N < M, a complete output host buffer can not be produced directly. The beginning of the first produced host output number must be filled with null frames, obtaining the following scheme :

N

M

M

Input host buffer

Input user buffer

Output user buffer

added null frames | Output host buffer

N

Some remaining frames have to be kept during one cycle to be used during the next cycle both into the user input buffer and the user output buffer. Four values are used to describe the state of the system :

- Host input buffer = the number of frames available in the host input buffer
- User input buffer = the number of frames possibly kept in the user input buffer between two consecutive host callbacks
- User output buffer = the number of frames possibly kept in the user output buffer between two consecutive host callbacks
- Host output buffer = the number of frames written into the host ouput buffer

Let take a real example with M = 100 and N = 70. To be able to complete the first host ouput buffer we could choose M-N = 30, and we can display the state of the system at the beginning and the end of each host callback :

Beginning of callback 1

Host input buffer = 100 : the host input buffer is full
User input buffer = 0
User ouput buffer = 0
Host ouput buffer = 30 : added null frames for the first ouput buffer

After one adapdation cycle, the system state is the following :

End of callback 1

Host input buffer = 0 : all input frames have been used
User input buffer = 30 : remaining host input frames (remainder of 100/70)
User ouput buffer = 0
Host ouput buffer = 70 + 30 added null frames = 100 ==> the host ouput buffer is full

Beginning of callback 2 : 100 new frames are received

Host input buffer = 100
User input buffer = 30 : frames kept from the previous cycle User ouput buffer = 0
Host ouput buffer = 0

End of callback 2

Host input buffer = 0
User input buffer = 60 : remainder of (100 + 30)/70
User ouput buffer = 70
Host ouput buffer = 0

There is a problem here because a complete host ouput buffer can not be produced (because 70 <100). Thus the value has to be choosen to guarantee that a complete host ouput buffer can be produced at each cycle. We could just add N null frames to start the process. But adding null frames at the beginning of the first host output buffer (that is shifting the whole ouput stream), increases the global latency.

Thus we would like to find the smallest number of null frames that must be put in the first output host buffer to guarantee that the audio streaming process can be done. This value can be found by doing the following reasoning :

- At the first host callback : M frames are received, and M/N PortAudio callback can be called. The minimum number of needed frames to complete a full M ouput buffer is M%N (where % gives the remainder of M/N).

M

N N

- At the second host callback : the total number of received frames from the beginning is 2*M frames. The total number of user callback that can be called is (2*M)/N. The minimum number of needed frames
to complete 2*M ouput buffers is (2*M)%N.

M

N

M

N | N | N | N
- At the n host callback : the total number of received frames from the beginning is n*M frames. The total number of user callback that can be called is (n*M)/N. The minimum number of needed frames to complete n*M ouput buffers is (n*M)%N.

Thus the set of all remainders of M/N, (2*M)/N....(n*M)/N can be computed. The computation must be done until the PPCM of M and N is reached. Indeed we can see that at PPCM(M,N)+M we have :

[PPCM(M,N)+M]/N = PPCM(M,N)/N + M/N = a + M/N where a is an integer value

So the remainder of [PPCM(M,N)+M]/N is the same of the remainder of M/N, thus the set of remainder values is now complete because the same cycle of values start again. Going from M, 2*M... up to the PPCM (M,N), a series of values is obtained. These values are the minimum frame numbers that should be added at each step to guarantee that the required number of buffer of size M can be produced.

To be sure that the required number of buffers of size M can be produced at each cycle, the maximum of this set of values must be choosen.

- the minimum number of frame to be added to the first host ouput buffer is the maximum of the serie (n*M)%N computed from M up to PPCM (M,N).

### 3.4 Case 4 : host buffer size inferior of user buffer size

M

N

MN

M

Input host buffer

Input user buffer

Output user buffer

Output host buffer

The same reasoning can be used in this case, and we can show that the previously explained algorithm can also be used to compute the needed value.

M

M

Input host buffer

Input user buffer

Output user buffer

Output host buffer

N

N

added null frames

Here the null frames will be added to the beginning of the first user input buffer, so that the user callback can be called, and one host ouput buffer can be produced. Actually the adaptation algorithm can be used in the four different cases, where cases 1 and 2 are the more simple ones.

### 3.5 Performances

The used method guarantee that the latency added by buffer size adaptation is the smallest. It gives a pratical way to know the right value to be used, even if the gain in latency is usually small. Actually in the case when the host buffer size M is greater to the user buffer size N, and depending of the values M and N, the gain in latency can be up to N/2. Indeed the buffer size adaptation algorithm gives N-1 in the worst case and N/2 in the best case.

### 4 Implementation

The following implementation uses a CallbackAdaptor data structure that contains several variables needed during each adaptation cycle.

// Utilities for buffer size alignment computation

int PGCD (int a, int b) {return (b == 0) ? a : PGCD (b,a%b);} int PPCM (int a, int b) {return (a*b) / PGCD (a,b);}

// Takes the size of host buffer and user buffer : returns the number of frames needed for buffer alignment

int CalcFrameShift (int M, int N)
{
int res = 0;
for (int i = M; i < PPCM (M,N) ; i+=M) { res = max (res, i%N); } return res;
}

// Type for the audio callbacks

typedef int (audioCallback)
(void *inputBuffer, void *outputBuffer, int framesPerBuffer, void* userData);

// Data structure for callback adaptation

typedef struct {

float* userInputBuffer;
float* userOutputBuffer;

// Offset in host input buffer int hostInputBufferOffset; // Offset in host ouput buffer int hostOutputBufferOffset; // Offset in user input buffer int userInputBufferOffset; // Offset in user ouput buffer int userOutputBufferOffset;

int hostBufferSize;
int userBufferSize;
audioCallback* userCallback;

}CallbackAdaptor;

// Function to be provided to handle transfer of samples between host and user buffers

void CopyUser2Host (float* input, float* ouput, int frames)
{
/* To be completed */
printf ("CopyUser2Host : %d\n",frames);
}

// Function to be provided to handle transfer of samples between user and host buffers

void CopyHost2User (float* input, float* ouput, int frames)
{
/* To be completed */
printf ("CopyHost2User : %d\n",frames);
}

// Allocates a new CallbackAdaptor :

CallbackAdaptor* MakeCallbackAdaptor (int M, int N, audioCallback* callback)
{
CallbackAdaptor* adaptor = (CallbackAdaptor*)malloc (sizeof(CallbackAdaptor));

// Allocation of user buffers
adaptor->userInputBuffer = (float*)malloc(N*sizeof(float)); adaptor->userOutputBuffer = (float*)malloc(N*sizeof(float));

adaptor->userCallback = callback; adaptor->hostBufferSize = M; adaptor->userBufferSize = N;
return adaptor;
}

// Computes the shift value used for the first ouput buffer : this value is used to initialize the write offset in the user input buffer or the host ouput buffer depending of M and N

void InitCallbackAdaptor (CallbackAdaptor* adaptor)
{
int frameShift = CalcFrameShift(adaptor->hostBufferSize,adaptor->userBufferSize);

if (adaptor->userBufferSize <= adaptor->hostBufferSize) {
adaptor->hostInputBufferOffset = 0; | // empty
adaptor->hostOutputBufferOffset = frameShift;
adaptor->userInputBufferOffset = 0; | // empty
adaptor->userOutputBufferOffset = adaptor->userBufferSize; | // empty
}else {
adaptor->hostInputBufferOffset = 0; | // empty
adaptor->hostOutputBufferOffset = 0; | // empty
adaptor->userInputBufferOffset = frameShift;
adaptor->userOutputBufferOffset = adaptor->userBufferSize; | // empty
}
}

// Delete a CallbackAdaptor

void DeleteCallbackAdaptor (CallbackAdaptor* adaptor)
{
if (adaptor->userInputBuffer) free (adaptor->userInputBuffer); if (adaptor->userOutputBuffer) free (adaptor->userOutputBuffer); free(adaptor);
}

// Internal function used by HostCallback

void OutputUser2Host(CallbackAdaptor* adaptor, float* hostOuputBuffer, int framesNumber) {
if (framesNumber > 0) {

CopyUser2Host(adaptor->userOutputBuffer, hostOuputBuffer, framesNumber);

adaptor->hostOutputBufferOffset += framesNumber; adaptor->userOutputBufferOffset += framesNumber;
}
}

// Callback adpatation : does the host to user buffer transfer. Call of the the user callback, user to host buffer transfer

void HostCallback
(void* InputBuffer, void* OuputBuffer, int framesPerBuffer, void* userData)
{
float* hostInputBuffer = (float*) InputBuffer;
float* hostOuputBuffer = (float*) OuputBuffer;

CallbackAdaptor* adaptor = (CallbackAdaptor*)userData;

// number of frames available into the host input buffer long framesInputHostBuffer = framesPerBuffer;
// number of frames needed to complete the user input buffer long framesInputUserBuffer;
// number of frames needed to complete the host output buffer long framesOutputHostBuffer;
// number of frames available into the user output buffer long framesOuputUserBuffer;
long tmp;

/* Fill host output with remaining frames in user output */ framesOutputHostBuffer = framesPerBuffer - adaptor->hostOutputBufferOffset; framesOuputUserBuffer = adaptor->userBufferSize - adaptor->userOutputBufferOffset; tmp = min(framesOutputHostBuffer, framesOuputUserBuffer);
framesOutputHostBuffer -= tmp;
OutputUser2Host(adaptor,hostOuputBuffer, tmp);

/* Available frames in hostInputBuffer */
while (framesInputHostBuffer > 0) {

/* Number of frames needed to complete an user input buffer */ framesInputUserBuffer = adaptor->userBufferSize - adaptor->userInputBufferOffset;

if (framesInputHostBuffer >= framesInputUserBuffer) {

CopyHost2User (hostInputBuffer, adaptor->userInputBuffer, framesInputUserBuffer);

/* Call user callback */
adaptor->userCallback(adaptor->userInputBuffer, adaptor->userOutputBuffer, adaptor-userBufferSize, NULL);

/* Full user ouput buffer : write offset */ adaptor->userOutputBufferOffset = 0;

/* Empty user input buffer : read offset */ adaptor->userInputBufferOffset = 0;

tmp = min (adaptor->userBufferSize,framesOutputHostBuffer); OutputUser2Host(adaptor, hostOuputBuffer, tmp);

framesOutputHostBuffer -= tmp;
framesInputHostBuffer -= framesInputUserBuffer; adaptor->hostInputBufferOffset += framesInputUserBuffer;

}else {

CopyHost2User (hostInputBuffer, adaptor->userInputBuffer,framesInputHostBuffer);

adaptor->userInputBufferOffset += framesInputHostBuffer; adaptor->hostInputBufferOffset += framesInputHostBuffer;

framesInputHostBuffer = 0;
}
}
}

// The following functions are used to simulate a real system :

// To “simulate” the hardware interrupt : the host input buffer has been filled, it is now full void ReadInputHostBuffer(CallbackAdaptor* adaptor)
{
adaptor->hostInputBufferOffset = 0; // full host input buffer;
}

// To “simulate” the hardware interrupt : the host ouput buffer has been used, it is now empty

void WriteOutputHostBuffer(CallbackAdaptor* adaptor)
{
adaptor->hostOutputBufferOffset = 0; // empty host output buffer;
}

// Prints the state of the CallbackAdaptor structure

void PrintCallbackAdaptorState(CallbackAdaptor* adaptor)
{
printf ("Adaptor : hostInputBufferOffset %ld \n", adaptor->hostInputBufferOffset); printf ("Adaptor : hostOuputBufferOffset %ld \n", adaptor->hostOutputBufferOffset); printf ("Adaptor : userInputBufferOffset %ld \n", adaptor->userInputBufferOffset); printf ("Adaptor : userOuputBufferOffset %ld \n", adaptor->userOutputBufferOffset); }

// The user callback

int UserCallback
(void *inputBuffer, void *outputBuffer,int framesPerBuffer, void* userData) {
printf ("UserCallback : framesPerBuffer %d \n",framesPerBuffer);
}

// General simuation function

void Simulate (int M, int N)
{
int i,n = PPCM(M,N)/M+1;
CallbackAdaptor* adaptor = MakeCallbackAdaptor(M, N, UserCallback); InitCallbackAdaptor(adaptor);

// Allocation of host buffers
float* hostInputBuffer = (float* )malloc(M*sizeof(float));
float* hostOutputBuffer = (float* )malloc(M*sizeof(float));

printf ("\n-------------------------------------------- \n"); printf ("Simulation of Callback adaptor [%d,%d]\n", M, N);

for (i = 0; i< n ; i++) {
printf ("----------------- \n");
printf ("Callback %d \n",i);
printf ("----------------- \n"); ReadInputHostBuffer(adaptor); PrintCallbackAdaptorState(adaptor); HostCallback(hostInputBuffer,hostOutputBuffer,M,adaptor); PrintCallbackAdaptorState(adaptor); WriteOutputHostBuffer(adaptor);
}

DeleteCallbackAdaptor(adaptor);

free(hostInputBuffer);
free(hostOutputBuffer);
}

int main ()
{
printf ("\n---------------------------\n"); printf ("Simulation of Callback adaptor\n"); Simulate(2016,512);
Simulate(128,250);
printf ("End of simulation \n");
}

### 5 Conclusion

A callback adaptation technique has been presented. It allows to use two callbacks that use buffers of different sizes, and guarantee the lowest latency added by buffer size adaptation. This technique has been successfully used for the port of the PortAudio API on ASIO described in [Letz 2001].

References

[ASIO 97-99] Asio 2.0 Audio Streaming Input Ouput Developement kit. Steinberg (c) 1997-1999 Steinberg Soft -und harware GmbH.

[Bencina, Burk 2001] Ross bencina, Phil Burk “PortAudio : an Open Source Cross Platform Audio API” Proceedings of the International Computer Music Conference 2001, International Computer Music Association, San Francisco.

[Letz 2001] Stephane Letz “Porting PortAudio API on ASIO” GRAME - Computer Music Research Lab. Technical Note - 01-11-06

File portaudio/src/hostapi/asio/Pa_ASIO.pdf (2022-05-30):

GRAME - Computer Music Research Lab.

### Technical Note - 01-11-06

# Porting PortAudio API on ASIO

Stéphane Letz
November 2001
Grame - Computer Music Research Laboratory 9, rue du Garet BP 1185 69202 FR - LYON Cedex 01 letz@grame.fr

Abstract

This document describes a port of the PortAudio API using the ASIO API on Macintosh and Windows. It explains technical choices used, buffer size adaptation techniques that guarantee minimal additional latency, results and limitations.

### 1 The ASIO API

ASIO (Audio Streaming Input Ouput) is an API defined and proposed by Steinberg. It addesses the area of efficient audio processing, synchronization, low latency and extentibility on the hardware side. ASIO allows the handling of multi-channel professional audio cards, and different sample rates (32 kHz to 96 kHz), different sample formats (16, 24, 32 bits of 32/64 floating point formats). ASIO is available on MacOS and Windows.

### 2 PortAudio API

PortAudio is a library that provides streaming audio input and output. It is a cross-platform API that works on Windows, Macintosh, Linux, SGI, FreeBSD and BeOS. This means that programs that need to process or generate an audio signal, can run on several different computers just by recompiling the source code. PortAudio is intended to promote the exchange of audio synthesis software between developers on different platforms.

### 3 Technical choices

Porting PortAudio to ASIO means that some technical choices have to be made. The life cycle of the ASIO driver must be “mapped” to the life cycle of a PortAudio application. Each PortAudio function will be implemented using one or more ASIO functions.

### 3.1 Life cycle of the ASIO driver :

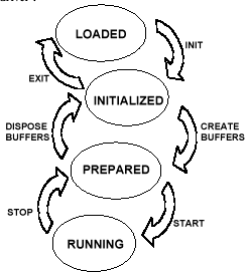
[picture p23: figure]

The most important functions that must be used to open and use the ASIO driver are the following :

- From Loaded to Initialized state : ASIOInit
- From Initialized to Prepared state : ASIOCreateBuffers
- From Prepared to Running state : ASIOStart

ASIO drivers are callback based. In their running state, an audio callback will be called with the index of the double buffer half (0 or 1) which has to be processed by the application.

The most important functions that must be used to close the ASIO driver are the following :

- From Running to Prepared state : ASIOStop
- From Prepared to Initialized state : ASIODisposeBuffers
- From Initialized to Loaded state : ASIOExit

### 3.2 Life cycle of an PortAudio application

A standard PortAudio application uses the following functions during it’s life time :

- Pa_Initialize : to initialize the library
- Pa_OpenSteam : to access the diver and open a stream
- Pa_StartStream : to start audio processing
- Pa_StopStream : to stop audio processing
- Pa_CloseStream : to deallocate the stream structure
- Pa_Terminate : to deallocate the library structures

### 3.3 PortAudio to ASIO mapping

Most PortAudio API functions have an internal platform dependant version that must be implemented on each platform. They are named PaHost_XXXX. Aditional functions needed for the PortAudio implementation on ASIO are named Pa_ASIO_XXX. Each external PortAudio API function is implemented using a PaHost_XXXX function that may use other functions of the PortAudio API. PaHost_XXXX functions call one or several “glue” functions named Pa_ASIO_XXX that in turn call one or several ASIO API functions.
The following table describes the “mapping “ between “ PortAudio functions and ASIO functions :
External PortAudio API Implementation PortAudio API | Glue | ASIO API
Pa_Initialize | PaHost_Init , | Pa_ASIO_QueryDeviceInfo loadAsioDriver
| Pa_CountDevice | | ASIOInit ASIOGetChannels ASIOCanSampleRate ASIOGetChannelInfo
Pa_OpenSteam | PaHost_OpenStream | Pa_ASIO_loadDevice | loadAsioDriver ASIOInit ASIOGetChannels ASIOGetBufferSize
| PaHost_CalcNumHostBuffers
| | Pa_ASIO_CreateBuffers | ASIOCreateBuffers ASIOGetLatencies ASIOSetSampleRate

Pa_StartStream | PaHost_StartOutput
| PaHost_StartInput
| PaHost_StartEngine | ASIOStart
Pa_StopStream | PaHost_StopOutput
| PaHost_StopInput
| PaHost_StopEngine | ASIOStop
Pa_CloseStream | PaHost_CloseStream | ASIODisposeBuffers
| | ASIOExit
Pa_Terminate | PaHost_Term | removeCurrentDriver

### 3.3.1 Opening : getting device information

On Macintosh ASIO drivers are files located in a special folder called “ASIO Drivers” located in the application folder. These ASIO drivers can easilly be changed simply by moving ASIO drivers files to and from the ASIO Drivers folder. Some utilities functions are available in the the ASIO SDK :

- loadDriver load an ASIO driver in memory given it’s name
- getDriverNames returns the name of all available drivers

The internal function Pa_ASIO_QueryDeviceInfo use them to get access to the available ASIO drivers on the machine.

### 3.3.2 Configuration

Each ASIO driver has to be loaded, configurated by choosing the number of input/ouput channels, and the size of ASIO internal buffers. Selection and configuration of the ASIO driver is done in PaHost_OpenStream :

- the ASIO driver corresponding to the selected device is loaded using Pa_ASIO_loadDevice which calls ASIOInit
- the ASIO driver sample rate is configurated using ASIOSetSampleRate
- the ASIO driver buffer size is computed using PaHost_CalcNumHostBuffers
- ASIO buffers, channels and callback are allocated and configured using Pa_ASIO_CreateBuffers which calls ASIOCreateBuffers

### 3.3.3 Start/Stop

The PaHost_StartEngine function directly calls the ASIOStart function to start the audio streaming process. The PaHost_StopEngine function directly calls the ASIOStop function to stop the audio streaming process.

### 3.3.4 Closing

The PaHost_CloseStream function will call ASIODisposeBuffers then ASIOExit.

### 3.3.5 Sample count

ASIO gives the sample position in the audio stream at each callback. This information is directly used to update the pahsc_NumFramesDone variable that is returned by the PortAudio Pa_StreamTime function.

### 3.3.6 Audio callback

The ASIO driver calls a bufferSwith or bufferSwitchTimeInfo callback with the index of the double buffer half (0 or 1) which has to be processed, to the application. Upon return of the callback, the application has read all input data and provided all output data. In this document we will use the name host buffers for ASIO internal buffers and user buffers for PortAudio buffers.

After the initialisation steps, the ASIO callback will basically do the following operations in a full-duplex case :

- transfer samples from the ASIO host input buffer to the PortAudio user input buffer. This transfer implies interleaving and possible samples conversion in the current implementation.
- if the PortAudio user input buffer is full, call the PortAudio callback which will produce a user output buffer.
- transfer samples from the PortAudio user ouput buffer into the ASIO host ouput buffer. This transfer needs “de-interleaving” and possible sample conversion in the current implementation.

These operations may be done several time depending of the ASIO and PortAudio buffer sizes that are used. But at each ASIO callback, all samples from the host input buffer must be consumed and a complete host ouput buffer has to be produced.

### 4 Buffer size adaptation techniques

A PortAudio program opens a stream by defining a buffer size (expressed in frames) that the audio callback must receive with the exact number of required frames. On the driver side, ASIO gives 3 values : minimum size, preferred size and maximum size for its internal buffers. Some ASIO drivers give the same value for minimum, prefered and maximum buffer size and only an external tool can be used to change the host buffer size when the driver is not running (M Audio Delta 10x10 for example)

The main difference with other implementation or the PortAudio API is that ASIO imposes it’s buffer size, thus in the general case buffer size adaptation techniques have to be used. We want to use the minimum host buffer size especially in full-duplex applications when the minimal latency is often necessary.

### 4.1 Computing host buffer size

Knowing the required user buffer size and the number of buffers, the first step is to compute the host buffer size that is most adapted using the following method :

- computes the global requested user buffer size = numBuffer * userBufferSize
- if the global requested user size is inside the minimum/maximum host size range, take : host buffer size = requested user buffer size
- otherwise
- if requested user buffer size < miminum host buffer size take the first
multiple of requested user size immediatly superior of miminum host buffer size if possible
- otherwise take host buffer size = miminum host buffer size
- if requested user buffer size > maximum host buffer size take the first divisor
of requested user buffer size immediatly inferior of miminum host buffer size if possible
- otherwise take host buffer size = maximum host buffer size
- align host buffer size to be a power of 2 if the ASIO drivers requires it

### 4.2 Buffer size adapdation techniques

A specific technique that allows to adapt two callback using buffers of different sizes has been developed. It is explained in detail in [Letz 2001].

### 5 Implementation

This general algorithm (finding the smallest number of frames for ouput shift) is actually usable in all cases : simple ones when M and N are multiple or divisors of each other and the more complex ones. In the implementation, several variables are used during the audio computation :

- pahsc_userInputBufferFrameOffset : position in input user buffer

- pahsc_userOutputBufferFrameOffset : position in output user buffer
- pahsc_hostOutputBufferFrameOffset : position in output ASIO buffer

At initialization time, a Pa_ASIO_CalcFrameShift function that implements the algorithm is used to compute the frame number used for the first host ouput buffer :

- when M>N we define pahsc_OutputBufferOffset = Pa_ASIO_CalcFrameShift(M,N). This value is used to shift the pahsc_hostOutputBufferFrameOffset variable (host ouput write offset)
- when M<N we define pahsc_InputBufferOffset = Pa_ASIO_CalcFrameShift(M,N). This value is used to shift the pahsc_userInputBufferFrameOffset variable (user input write offset)

### 5.1 Total Latency

After host buffer creation the ASIOGetLatencies function can be used to know the input and ouput latencies. Depending on the drivers internal implementation (if it writes directly to a DMA buffer or not) ouput latency will be 1 or 2 blocks. The total I/O latency will be :

ASIO input latency + ASIO output latency + host/user buffers size adaptation latency

### 5.2 Adtional function description

Here is the description of the most important functions of the PortAudio on ASIO implementation :

- Pa_ASIO_QueryDeviceInfo : load all available ASIO drivers and get information on all of them.
- Pa_ASIO_loadDevice : load the ASIO driver corresponding to the required device number.
- Pa_ASIO_CreateBuffers : create ASIO buffers and initialise ASIO channels.
- Pa_ASIO_Convert_SampleFormat : convert an ASIO native format sample into the corresponding PortAudio sample format.
- Pa_ASIO_Convert_Inter_Input : convert ASIO native buffers into PortAudio user buffers, do sample conversion and interleaving.
- Pa_ASIO_Convert_Inter_Ouput : convert PortAudio user buffers into ASIO native buffers, do sample conversion and “de-interleaving”.
- Pa_ASIO_Callback_Input, Pa_ASIO_Callback_Output : called by the native ASIO callback, do the buffer adpatation code, host to user buffer conversion, call of the PortAudio callback, production of the host ouput buffer.
- PaHost_CalcNumHostBuffers : from the userBufferSize and the numOfBuffers values, computes the most adpated hostBufferSize to be used for ASIO internal buffers creation.
- Input_Int16_Flot32 and functions of the same family : host to user buffer conversion.
- Output_Float32_Int16 and functions of the same family : user to host buffer conversion.

### 6 Limitations and possible improvements

### 6.1 Getting the smallest latency

To get minimal latencies in all cases, a better solution would be to allow the PortAudio user to know the host’s choosen buffer size. Thus, an application that wants small latency and does not care what the user buffer size’s can take the user buffer size defined in Pa_OpenStream to be exactly equal to the host buffer size.

6.2 Interleaved, non-interleaved mode.

The ASIO buffers are not interleaved. Because PortAudio currently use only interleaved buffers, “de-interleaving” has to be done when converting ASIO buffers into user buffers, and the contrary at the ouput. This process is mixed with sample conversion.
A possible improvement is to extend PortAudio to allow the use of non-interleaved buffers. Thus de-interleaving is not longer necessary and fast vector operations can be used on some architectures (Intel SSE or PowerPC Altivec) to improve to speed of sample conversions.

### 6.3 Muliple buffers

When opening a PortAudio stream, a number of buffers can be specified. In the current implementation this number is used when computing the host buffer size. Specifying a small user buffer size and several buffers will result in a bigger host buffer size but that will always be limited by the maximum possible host buffer size.

### 6.4 Stream stopping

The current implementation does not distinguish between aborting and stopping the audio stream. Aborting should immediatly ends the stream and stopping should let the stream playing until the end of all buffers. The current implementation aborts the stream in all cases.

### 6.5 Handling multiple audio cards

ASIO does not allow to load and use several drivers at the same time. Thus only one audio stream can be opened using the currently loaded driver at a given time.

### 7 Conclusion

A port of the PortAudio API using the ASIO API on Macintosh and Windows has been done sucessfully, thus giving PortAudio based applications the possibility to be used with professional multi-channel cards on Macintosh and Windows. The described implementation handles the complete PortAudio API with some limitations that may be removed by extending the PortAudio API. Thanks to Phil Burk for his help and advice during this work, and to Nick Dodkovsky, David Viens and Maurice Cameron for testing on Windows.

References

[ASIO 97-99] Asio 2.0 Audio Streaming Input Ouput Developement kit. Steinberg (c) 1997-1999 Steinberg Soft -und harware GmbH.

[Bencina, Burk 2001] Ross bencina, Phil Burk “PortAudio : an Open Source Cross Platform Audio API” Proceedings of the International Computer Music Conference 2001, International Computer Music Association, San Francisco.

[Letz 2001] Stephane Letz “Callback adapdation techniques” GRAME - Computer Music Research Lab. Technical Note - 01-11-07

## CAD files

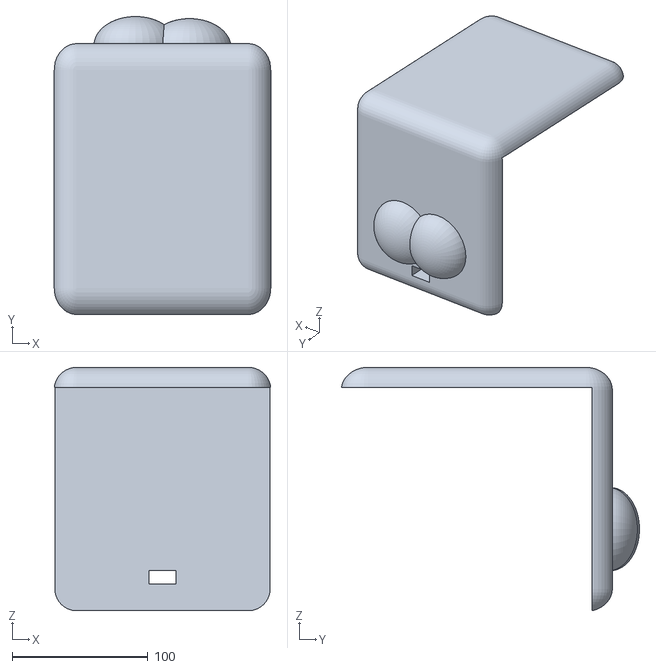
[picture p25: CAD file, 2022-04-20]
HardwareDesign/Models/cuerpo2.stl
159.7 x 219.8 x 179.5

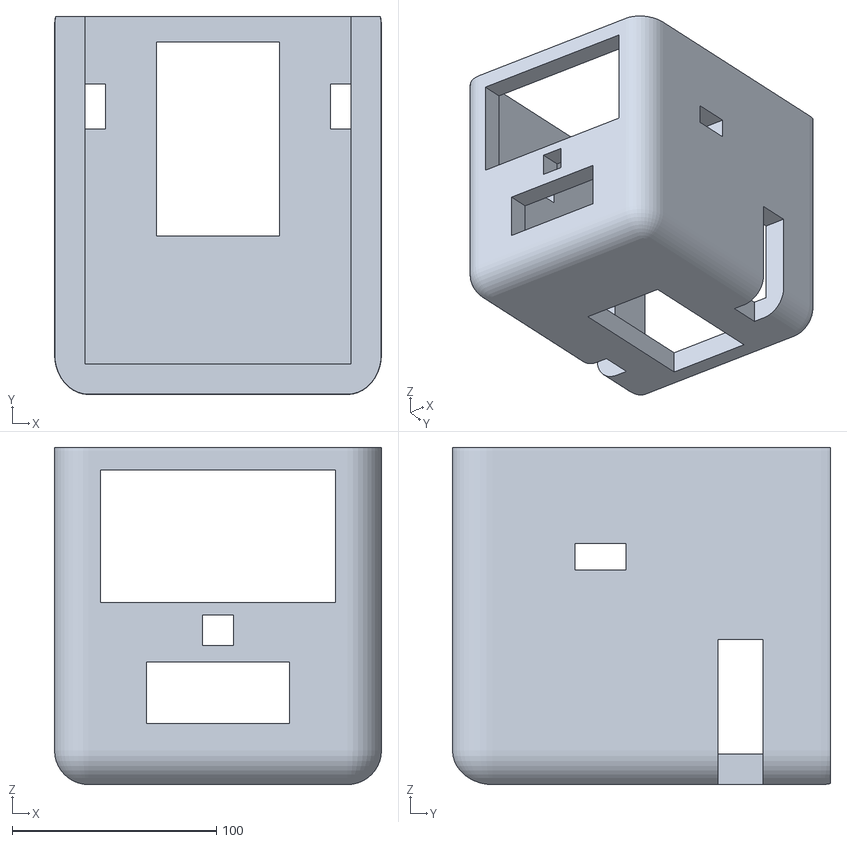
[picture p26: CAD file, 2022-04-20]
HardwareDesign/Models/cuerpo1.stl
160.0 x 185.0 x 165.0

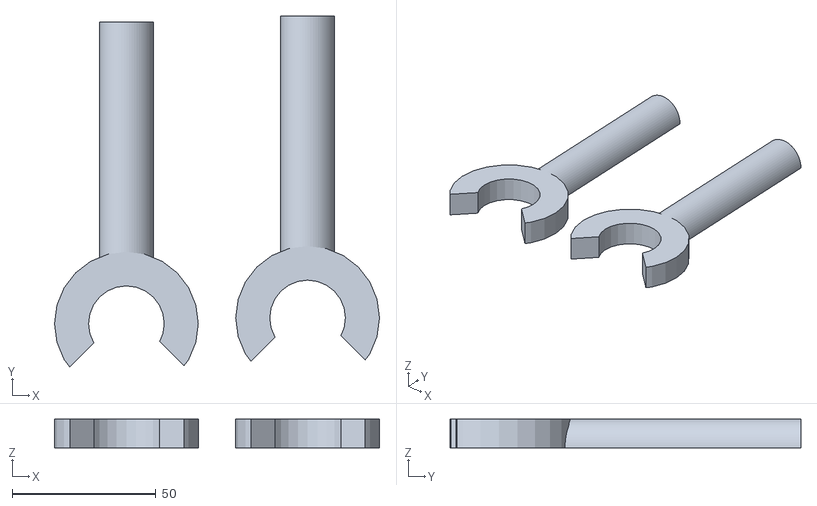
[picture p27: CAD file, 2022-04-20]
HardwareDesign/Models/brazos.stl
113.0 x 122.0 x 10.0

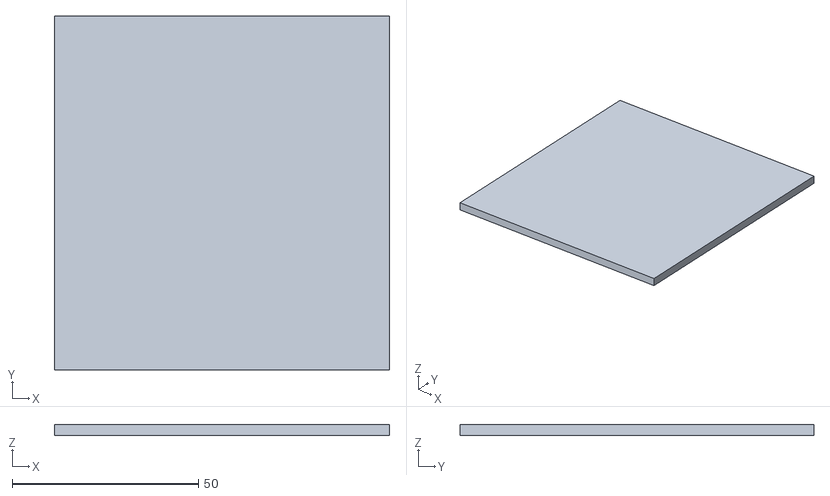
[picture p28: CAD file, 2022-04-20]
HardwareDesign/Models/tapa.stl
90.0 x 95.0 x 3.00

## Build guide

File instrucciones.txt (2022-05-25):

Frase	                    ID
hola detecta objeto	        1
hola detecta emocion	    2
hola gira a la derecha	    3
hola gira a la izquierda	4
hola hora	                5
hola ponte {emocion}	    6
hola ponte enfadado	        7
hola cuentame chiste	    8
hola gira	                9
hola donde estoy	        10
hola avanza	                11
hola para	                -1
	
Sensor input	
Caida	                    -2
Camara oscura	            -3

Operaciones aritmeticas

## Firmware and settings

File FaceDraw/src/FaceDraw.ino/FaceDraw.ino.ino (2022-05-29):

#include <UTFT.h> 

#ifdef __arm__
// should use uinstd.h to define sbrk but Due causes a conflict
extern "C" char* sbrk(int incr);
#else  // __ARM__
extern char *__brkval;
#endif  // __arm__

int freeMemory() {
  char top;
#ifdef __arm__
  return &top - reinterpret_cast<char*>(sbrk(0));
#elif defined(CORE_TEENSY) || (ARDUINO > 103 && ARDUINO != 151)
  return &top - __brkval;
#else  // __arm__
  return __brkval ? &top - __brkval : &top - __malloc_heap_start;
#endif  // __arm__
}

// 320x240

UTFT myGLCD(ILI9341_16,38,39,40,41);

unsigned char animacion_actual = 0;

const unsigned char enfadado[] PROGMEM = { 96, 136, 0, 0, 1, 0, 0, 1, 3, 1, 1, 1, 3, 3, 4, 3, 4, 1, 1, 2, 3, 2, 0, 0, 0, 0, 0, 0, 1, 1, 0, 3, 4, 8, 8, 17, 2, 0, 3, 11, 2, 0, 9, 18, 14, 15, 26, 11, 13, 4, 4, 0, 0, 1, 1, 0, 1, 0, 0, 0, 0, 0, 0, 0, 0, 0, 0, 0, 0, 0, 0, 0, 0, 0, 0, 0, 0, 0, 0, 1, 0, 0, 2, 0, 0, 4, 12, 31, 25, 35, 9, 10, 11, 19, 4, 1, 3, 7, 7, 255, 7, 8, 255, 7, 9, 255, 7, 10, 255, 7, 11, 255, 7, 12, 255, 7, 19, 255, 7, 20, 255, 7, 21, 255, 7, 22, 255, 7, 23, 255, 7, 24, 255, 8, 6, 255, 8, 7, 255, 8, 8, 255, 8, 9, 255, 8, 10, 255, 8, 11, 255, 8, 12, 255, 8, 13, 255, 8, 18, 255, 8, 19, 255, 8, 20, 255, 8, 21, 255, 8, 22, 255, 8, 23, 255, 8, 24, 255, 8, 25, 255, 9, 6, 255, 9, 7, 255, 9, 8, 255, 9, 9, 255, 9, 10, 255, 9, 11, 255, 9, 12, 255, 9, 13, 255, 9, 18, 255, 9, 19, 255, 9, 20, 255, 9, 21, 255, 9, 22, 255, 9, 23, 255, 9, 24, 255, 9, 25, 255, 10, 6, 255, 10, 7, 255, 10, 8, 255, 10, 9, 255, 10, 10, 255, 10, 11, 255, 10, 12, 255, 10, 13, 255, 10, 18, 255, 10, 19, 255, 10, 20, 255, 10, 21, 255, 10, 22, 255, 10, 23, 255, 10, 24, 255, 10, 25, 255, 11, 6, 255, 11, 7, 255, 11, 8, 255, 11, 9, 255, 11, 10, 255, 11, 11, 255, 11, 12, 255, 11, 13, 255, 11, 18, 255, 11, 19, 255, 11, 20, 255, 11, 21, 255, 11, 22, 255, 11, 23, 255, 11, 24, 255, 11, 25, 255, 12, 6, 255, 12, 7, 255, 12, 8, 255, 12, 9, 255, 12, 10, 255, 12, 11, 255, 12, 12, 255, 12, 13, 255, 12, 18, 255, 12, 19, 255, 12, 20, 255, 12, 21, 255, 12, 22, 255, 12, 23, 255, 12, 24, 255, 12, 25, 255, 13, 6, 255, 13, 7, 255, 13, 8, 255, 13, 9, 255, 13, 10, 255, 13, 11, 255, 13, 12, 255, 13, 13, 255, 13, 18, 255, 13, 19, 255, 13, 20, 255, 13, 21, 255, 13, 22, 255, 13, 23, 255, 13, 24, 255, 13, 25, 255, 14, 6, 255, 14, 7, 255, 14, 8, 255, 14, 9, 255, 14, 10, 255, 14, 11, 255, 14, 12, 255, 14, 13, 255, 14, 18, 255, 14, 19, 255, 14, 20, 255, 14, 21, 255, 14, 22, 255, 14, 23, 255, 14, 24, 255, 14, 25, 255, 15, 7, 255, 15, 8, 255, 15, 9, 255, 15, 10, 255, 15, 11, 255, 15, 12, 255, 15, 19, 255, 15, 20, 255, 15, 21, 255, 15, 22, 255, 15, 23, 255, 15, 24, 255, 15, 18, 255, 7, 18, 255, 7, 13, 255, 7, 25, 255, 15, 13, 255, 15, 25, 255, 7, 6, 255, 15, 6, 255, 11, 14, 255, 11, 17, 255, 12, 17, 255, 10, 14, 255, 10, 17, 255, 12, 14, 255, 9, 17, 255, 11, 26, 255, 13, 14, 255, 13, 17, 255, 9, 14, 255, 10, 26, 255, 12, 26, 255, 9, 26, 255, 10, 5, 255, 11, 5, 255, 12, 5, 255, 9, 5, 255, 13, 26, 255, 8, 14, 255, 13, 5, 255, 8, 17, 255, 8, 26, 255, 14, 17, 255, 8, 5, 255, 14, 14, 255, 14, 26, 255, 14, 26, 0, 6, 10, 255, 6, 21, 255, 6, 22, 255, 6, 9, 255, 8, 5, 0, 14, 14, 0, 14, 17, 0, 6, 8, 255, 6, 11, 255, 6, 20, 255, 6, 23, 255, 8, 14, 0, 8, 17, 0, 8, 26, 0, 13, 5, 0, 6, 12, 255, 6, 19, 255, 9, 5, 0, 10, 5, 0, 12, 5, 0, 13, 14, 0, 13, 17, 0, 13, 26, 0, 6, 7, 255, 6, 24, 255, 9, 14, 0, 9, 17, 0, 9, 26, 0, 10, 14, 0, 10, 17, 0, 10, 26, 0, 11, 5, 0, 11, 17, 0, 11, 26, 0, 12, 14, 0, 12, 17, 0, 12, 26, 0, 15, 6, 0, 15, 13, 0, 15, 25, 0, 11, 14, 0, 15, 18, 0, 5, 10, 255, 5, 21, 255, 5, 22, 255, 5, 8, 255, 5, 9, 255, 5, 11, 255, 5, 20, 255, 5, 23, 255, 14, 6, 0, 14, 13, 0, 14, 25, 0, 15, 7, 0, 15, 12, 0, 15, 24, 0, 14, 18, 0, 15, 19, 0, 5, 8, 0, 5, 9, 0, 5, 10, 0, 5, 11, 0, 5, 20, 0, 5, 21, 0, 5, 22, 0, 5, 23, 0, 13, 6, 0, 6, 7, 0, 6, 8, 0, 6, 10, 0, 6, 11, 0, 6, 12, 0, 6, 19, 0, 6, 20, 0, 6, 21, 0, 6, 23, 0, 6, 24, 0, 7, 6, 0, 7, 13, 0, 7, 18, 0, 7, 25, 0, 13, 6, 255, 14, 13, 255, 14, 18, 255, 15, 19, 255, 6, 9, 0, 6, 22, 0, 7, 7, 0, 7, 10, 0, 7, 11, 0, 7, 12, 0, 7, 19, 0, 7, 20, 0, 7, 21, 0, 7, 24, 0, 8, 6, 0, 8, 13, 0, 8, 18, 0, 15, 12, 255, 7, 8, 0, 7, 9, 0, 7, 22, 0, 7, 23, 0, 8, 10, 0, 8, 11, 0, 8, 12, 0, 8, 19, 0, 8, 20, 0, 8, 21, 0, 8, 25, 0, 9, 13, 0, 9, 18, 0, 15, 7, 255, 15, 24, 255, 8, 7, 0, 8, 8, 0, 8, 9, 0, 8, 22, 0, 8, 23, 0, 8, 24, 0, 9, 6, 0, 9, 10, 0, 9, 11, 0, 9, 12, 0, 9, 19, 0, 9, 20, 0, 9, 21, 0, 9, 25, 0, 10, 13, 0, 10, 18, 0, 12, 14, 255, 12, 17, 255, 13, 14, 255, 13, 17, 255, 14, 6, 255, 14, 14, 255, 14, 17, 255, 14, 25, 255, 15, 13, 255, 15, 18, 255, 9, 7, 0, 9, 8, 0, 9, 9, 0, 9, 22, 0, 9, 23, 0, 9, 24, 0, 10, 11, 0, 10, 12, 0, 10, 19, 0, 10, 20, 0, 11, 18, 0, 10, 6, 0, 10, 9, 0, 10, 10, 0, 10, 21, 0, 10, 22, 0, 10, 25, 0, 11, 12, 0, 11, 13, 0, 11, 19, 0, 12, 14, 0, 12, 17, 0, 15, 14, 255, 15, 17, 255, 10, 7, 0, 10, 8, 0, 10, 23, 0, 10, 24, 0, 11, 11, 0, 11, 20, 0, 12, 13, 0, 12, 18, 0, 11, 21, 0, 11, 10, 0, 12, 19, 0, 12, 19, 255, 11, 10, 255, 11, 21, 255, 11, 11, 255, 11, 20, 255, 12, 13, 255, 12, 18, 255, 10, 7, 255, 10, 8, 255, 10, 9, 255, 10, 22, 255, 10, 23, 255, 10, 24, 255, 11, 12, 255, 11, 19, 255, 12, 14, 255, 12, 17, 255, 15, 14, 0, 15, 17, 0, 9, 7, 255, 9, 8, 255, 9, 9, 255, 9, 10, 255, 9, 21, 255, 9, 22, 255, 9, 23, 255, 9, 24, 255, 10, 6, 255, 10, 10, 255, 10, 11, 255, 10, 12, 255, 10, 13, 255, 10, 18, 255, 10, 19, 255, 10, 20, 255, 10, 21, 255, 10, 25, 255, 11, 13, 255, 11, 18, 255, 12, 14, 0, 12, 17, 0, 13, 14, 0, 13, 17, 0, 14, 6, 0, 14, 14, 0, 14, 17, 0, 14, 25, 0, 15, 7, 0, 15, 13, 0, 15, 18, 0, 8, 7, 255, 8, 8, 255, 8, 9, 255, 8, 10, 255, 8, 11, 255, 8, 12, 255, 8, 19, 255, 8, 20, 255, 8, 21, 255, 8, 22, 255, 8, 23, 255, 8, 24, 255, 9, 6, 255, 9, 11, 255, 9, 12, 255, 9, 13, 255, 9, 18, 255, 9, 19, 255, 9, 20, 255, 9, 25, 255, 13, 6, 0, 13, 25, 0, 15, 12, 0, 15, 19, 0, 15, 24, 0, 6, 8, 255, 6, 9, 255, 6, 10, 255, 6, 11, 255, 6, 20, 255, 6, 21, 255, 6, 22, 255, 6, 23, 255, 7, 7, 255, 7, 8, 255, 7, 9, 255, 7, 10, 255, 7, 11, 255, 7, 12, 255, 7, 19, 255, 7, 20, 255, 7, 21, 255, 7, 22, 255, 7, 23, 255, 7, 24, 255, 8, 13, 255, 8, 18, 255, 9, 6, 0, 10, 6, 0, 11, 6, 0, 12, 6, 0, 12, 25, 0, 14, 13, 0, 14, 18, 0, 15, 8, 0, 15, 9, 0, 15, 10, 0, 15, 11, 0, 15, 20, 0, 15, 23, 0, 6, 7, 255, 6, 12, 255, 6, 19, 255, 6, 24, 255, 10, 25, 0, 11, 25, 0, 13, 13, 0, 15, 21, 0, 15, 22, 0, 7, 13, 255, 7, 18, 255, 8, 25, 255, 9, 6, 255, 10, 6, 255, 10, 25, 255, 11, 6, 255, 11, 25, 255, 12, 25, 255, 13, 13, 255, 7, 25, 255, 8, 6, 255, 12, 6, 255, 13, 6, 255, 13, 25, 255, 14, 13, 255, 14, 18, 255, 15, 9, 255, 15, 10, 255, 15, 21, 255, 15, 22, 255, 6, 7, 0, 6, 8, 0, 6, 9, 0, 6, 10, 0, 6, 11, 0, 6, 12, 0, 6, 19, 0, 6, 20, 0, 6, 21, 0, 6, 22, 0, 6, 23, 0, 6, 24, 0, 7, 6, 255, 14, 6, 255, 14, 25, 255, 15, 8, 255, 15, 11, 255, 15, 20, 255, 15, 23, 255, 15, 7, 255, 15, 12, 255, 15, 19, 255, 15, 24, 255, 7, 6, 0, 7, 13, 0, 7, 18, 0, 7, 25, 0, 0, 0, 0, 0, 0, 0, 0, 0, 0, 0, 0, 0, 0, 0, 0, 0, 0, 0, 0, 0, 0, 0, 0, 0, 0, 0, 0, 0, 0, 0, 0, 0, 0, 0, 0, 0, 0, 0, 0, 0, 0, 0, 0, 0, 0, 0, 0, 0, 0, 0, 0, 0, 0, 0, 0, 0, 0, 0, 0, 0, 0, 0, 0, 0, 0, 0, 0, 0, 0, 0, 0, 0, 0, 0, 0, 0, 0, 0, 0, 0, 0, 0, 0, 0, 0, 0, 0, 0, 0, 0, 0, 0, 0, 0, 0, 0, 0, 0, 0, 0, 0, 0, 0, 0, 0, 0, 0, 0, 0, 0, 0, 0, 0, 0, 0, 0, 0, 0, 0, 0, 0, 0, 0, 0, 0, 0, 0, 0, 0, 0, 0, 0, 0, 0, 0, 0, 0, 0, 0, 0, 0, 0, 0, 0, 0, 0, 0, 0, 0, 0, 0, 0, 0, 0, 0, 0, 0, 0, 0, 0, 0, 0, 0, 0, 0, 0, 0, 0, 0, 0, 0, 0, 0, 0, 0, 0, 0, 0, 0, 0, 0, 0, 0, 0, 0, 0, 0, 0, 0, 0, 0, 0, 0, 0, 0, 0, 0, 0, 0, 0, 0, 0, 0, 0, 0, 0, 0, 0, 0, 0, 0, 0, 0, 0, 0, 0, 0, 0, 0, 0, 0, 0, 0, 0, 0, 0, 0, 0, 0, 0, 0, 0, 0, 0, 0, 0, 0, 0, 0, 0, 0, 0, 0, 0, 0, 0, 0, 0, 0, 0, 0, 0, 0, 0, 0, 0, 0, 0, 0, 0, 0, 0, 0, 0, 0, 0, 0, 0, 0, 0, 0, 0, 0, 0, 0, 0, 0, 0, 0, 0, 0, 0, 0, 0, 0, 0, 0, 0, 0, 0, 0, 0, 0, 0, 0, 0, 0, 0, 0, 0};
const unsigned char corazon [] PROGMEM = { 94, 136, 0, 0, 1, 7, 25, 10, 30, 25, 50, 29, 16, 11, 12, 8, 12, 6, 0, 0, 3, 13, 10, 11, 11, 0, 8, 15, 17, 8, 0, 0, 2, 7, 2, 5, 0, 1, 2, 0, 0, 2, 3, 0, 8, 4, 6, 6, 0, 0, 0, 5, 4, 6, 4, 5, 3, 4, 7, 3, 6, 1, 0, 0, 0, 0, 8, 9, 7, 8, 6, 10, 2, 7, 19, 16, 25, 26, 23, 1, 11, 22, 1, 7, 17, 5, 3, 4, 1, 0, 0, 0, 0, 0, 0, 7, 7, 255, 7, 8, 255, 7, 9, 255, 7, 10, 255, 7, 11, 255, 7, 12, 255, 7, 19, 255, 7, 20, 255, 7, 21, 255, 7, 22, 255, 7, 23, 255, 7, 24, 255, 8, 6, 255, 8, 7, 255, 8, 8, 255, 8, 9, 255, 8, 10, 255, 8, 11, 255, 8, 12, 255, 8, 13, 255, 8, 18, 255, 8, 19, 255, 8, 20, 255, 8, 21, 255, 8, 22, 255, 8, 23, 255, 8, 24, 255, 8, 25, 255, 9, 6, 255, 9, 7, 255, 9, 8, 255, 9, 9, 255, 9, 10, 255, 9, 11, 255, 9, 12, 255, 9, 13, 255, 9, 18, 255, 9, 19, 255, 9, 20, 255, 9, 21, 255, 9, 22, 255, 9, 23, 255, 9, 24, 255, 9, 25, 255, 10, 6, 255, 10, 7, 255, 10, 8, 255, 10, 9, 255, 10, 10, 255, 10, 11, 255, 10, 12, 255, 10, 13, 255, 10, 18, 255, 10, 19, 255, 10, 20, 255, 10, 21, 255, 10, 22, 255, 10, 23, 255, 10, 24, 255, 10, 25, 255, 11, 6, 255, 11, 7, 255, 11, 8, 255, 11, 9, 255, 11, 10, 255, 11, 11, 255, 11, 12, 255, 11, 13, 255, 11, 18, 255, 11, 19, 255, 11, 20, 255, 11, 21, 255, 11, 22, 255, 11, 23, 255, 11, 24, 255, 11, 25, 255, 12, 6, 255, 12, 7, 255, 12, 8, 255, 12, 9, 255, 12, 10, 255, 12, 11, 255, 12, 12, 255, 12, 13, 255, 12, 18, 255, 12, 19, 255, 12, 20, 255, 12, 21, 255, 12, 22, 255, 12, 23, 255, 12, 24, 255, 12, 25, 255, 13, 6, 255, 13, 7, 255, 13, 8, 255, 13, 9, 255, 13, 10, 255, 13, 11, 255, 13, 12, 255, 13, 13, 255, 13, 18, 255, 13, 19, 255, 13, 20, 255, 13, 21, 255, 13, 22, 255, 13, 23, 255, 13, 24, 255, 13, 25, 255, 14, 6, 255, 14, 7, 255, 14, 8, 255, 14, 9, 255, 14, 10, 255, 14, 11, 255, 14, 12, 255, 14, 13, 255, 14, 18, 255, 14, 19, 255, 14, 20, 255, 14, 21, 255, 14, 22, 255, 14, 23, 255, 14, 24, 255, 14, 25, 255, 15, 7, 255, 15, 8, 255, 15, 9, 255, 15, 10, 255, 15, 11, 255, 15, 12, 255, 15, 19, 255, 15, 20, 255, 15, 21, 255, 15, 22, 255, 15, 23, 255, 15, 24, 255, 15, 18, 255, 7, 6, 255, 7, 13, 255, 7, 18, 255, 7, 25, 255, 15, 6, 255, 15, 13, 255, 15, 25, 255, 8, 5, 255, 8, 14, 255, 8, 26, 255, 9, 5, 255, 9, 14, 255, 9, 17, 255, 9, 26, 255, 10, 5, 255, 10, 14, 255, 10, 17, 255, 10, 26, 255, 11, 5, 255, 11, 14, 255, 11, 17, 255, 11, 26, 255, 12, 5, 255, 12, 14, 255, 12, 17, 255, 12, 26, 255, 13, 5, 255, 13, 14, 255, 13, 17, 255, 13, 26, 255, 14, 14, 255, 14, 17, 255, 6, 21, 255, 6, 22, 255, 7, 5, 255, 7, 26, 255, 8, 17, 255, 14, 5, 255, 14, 26, 255, 15, 14, 255, 15, 17, 255, 15, 26, 255, 6, 6, 255, 6, 7, 255, 6, 8, 255, 6, 9, 255, 6, 10, 255, 6, 11, 255, 6, 12, 255, 6, 13, 255, 6, 18, 255, 6, 19, 255, 6, 20, 255, 6, 23, 255, 6, 24, 255, 6, 25, 255, 7, 14, 255, 7, 17, 255, 15, 5, 255, 16, 7, 255, 16, 8, 255, 16, 9, 255, 16, 10, 255, 16, 11, 255, 16, 12, 255, 16, 19, 255, 16, 20, 255, 16, 21, 255, 16, 22, 255, 16, 23, 255, 16, 24, 255, 16, 25, 255, 6, 6, 0, 6, 7, 0, 6, 8, 0, 6, 9, 0, 6, 10, 0, 6, 11, 0, 6, 12, 0, 6, 13, 0, 6, 18, 0, 6, 19, 0, 6, 20, 0, 6, 21, 0, 6, 22, 0, 6, 23, 0, 6, 24, 0, 6, 25, 0, 7, 14, 0, 7, 17, 0, 15, 5, 0, 15, 14, 0, 15, 17, 0, 15, 26, 0, 16, 7, 0, 16, 12, 0, 16, 25, 0, 7, 5, 0, 7, 6, 0, 7, 9, 0, 7, 10, 0, 7, 13, 0, 7, 18, 0, 7, 21, 0, 7, 22, 0, 7, 25, 0, 7, 26, 0, 8, 5, 0, 8, 14, 0, 8, 17, 0, 8, 26, 0, 9, 5, 0, 9, 14, 0, 9, 17, 0, 9, 26, 0, 10, 5, 0, 10, 14, 0, 10, 17, 0, 10, 26, 0, 11, 5, 0, 11, 14, 0, 11, 17, 0, 11, 26, 0, 12, 5, 0, 12, 14, 0, 12, 17, 0, 12, 26, 0, 13, 5, 0, 13, 14, 0, 13, 17, 0, 13, 26, 0, 14, 5, 0, 14, 6, 0, 14, 14, 0, 14, 17, 0, 14, 25, 0, 14, 26, 0, 15, 6, 0, 15, 13, 0, 15, 18, 0, 15, 25, 0, 16, 8, 0, 16, 11, 0, 16, 19, 0, 16, 20, 0, 16, 23, 0, 16, 24, 0, 7, 11, 0, 7, 12, 0, 7, 19, 0, 7, 20, 0, 8, 6, 0, 8, 13, 0, 8, 18, 0, 8, 25, 0, 11, 6, 0, 11, 25, 0, 12, 6, 0, 12, 13, 0, 12, 18, 0, 12, 25, 0, 13, 6, 0, 13, 13, 0, 13, 18, 0, 13, 25, 0, 14, 7, 0, 14, 12, 0, 14, 13, 0, 14, 18, 0, 14, 19, 0, 14, 24, 0, 15, 7, 0, 15, 8, 0, 15, 12, 0, 15, 19, 0, 15, 24, 0, 7, 9, 255, 7, 11, 255, 7, 20, 255, 7, 22, 255, 9, 6, 0, 9, 25, 0, 10, 6, 0, 10, 25, 0, 11, 13, 0, 11, 18, 0, 13, 7, 0, 13, 24, 0, 15, 11, 0, 15, 20, 0, 15, 23, 0, 16, 9, 0, 7, 9, 0, 7, 11, 0, 7, 20, 0, 7, 22, 0, 8, 25, 255, 9, 6, 255, 9, 25, 255, 10, 6, 255, 10, 25, 255, 11, 13, 255, 11, 18, 255, 7, 7, 0, 7, 8, 0, 7, 23, 0, 7, 24, 0, 8, 6, 255, 11, 6, 255, 11, 25, 255, 12, 13, 255, 12, 18, 255, 13, 7, 255, 13, 24, 255, 16, 22, 0, 9, 5, 255, 9, 26, 255, 10, 5, 255, 10, 26, 255, 12, 6, 255, 12, 25, 255, 15, 11, 255, 15, 20, 255, 7, 7, 255, 7, 24, 255, 11, 5, 255, 11, 26, 255, 13, 13, 255, 13, 18, 255, 14, 12, 255, 14, 19, 255, 14, 24, 255, 15, 23, 255, 16, 10, 0, 16, 21, 0, 10, 14, 255, 10, 17, 255, 11, 14, 255, 11, 17, 255, 13, 25, 255, 14, 7, 255, 10, 17, 0, 13, 25, 0, 14, 7, 0, 7, 7, 0, 10, 14, 0, 11, 5, 0, 11, 14, 0, 11, 17, 0, 11, 26, 0, 13, 13, 0, 13, 18, 0, 14, 12, 0, 14, 19, 0, 14, 24, 0, 15, 23, 0, 16, 21, 255, 7, 24, 0, 9, 5, 0, 9, 26, 0, 10, 5, 0, 10, 26, 0, 12, 6, 0, 15, 11, 0, 15, 20, 0, 16, 10, 255, 16, 22, 255, 7, 7, 255, 7, 8, 255, 7, 23, 255, 7, 24, 255, 8, 6, 0, 11, 6, 0, 11, 25, 0, 12, 13, 0, 12, 18, 0, 12, 25, 0, 13, 7, 0, 7, 9, 255, 7, 11, 255, 7, 20, 255, 7, 22, 255, 8, 25, 0, 9, 6, 0, 10, 6, 0, 10, 25, 0, 11, 13, 0, 11, 18, 0, 13, 24, 0, 7, 9, 0, 7, 11, 0, 7, 20, 0, 9, 6, 255, 10, 6, 255, 10, 25, 255, 11, 13, 255, 11, 18, 255, 7, 7, 0, 7, 8, 0, 7, 22, 0, 7, 23, 0, 7, 24, 0, 8, 6, 255, 8, 25, 255, 11, 6, 255, 11, 25, 255, 12, 13, 255, 12, 18, 255, 12, 25, 255, 13, 7, 255, 13, 24, 255, 16, 22, 0, 7, 7, 255, 7, 24, 255, 9, 5, 255, 9, 26, 255, 10, 5, 255, 10, 26, 255, 11, 5, 255, 11, 26, 255, 12, 6, 255, 14, 12, 255, 14, 19, 255, 14, 24, 255, 15, 11, 255, 15, 20, 255, 15, 23, 255, 16, 10, 0, 16, 21, 0, 10, 14, 255, 10, 17, 255, 11, 14, 255, 11, 17, 255, 13, 13, 255, 13, 18, 255, 13, 25, 255, 14, 7, 255, 13, 25, 0, 14, 7, 0, 10, 14, 0, 10, 17, 0, 11, 14, 0, 11, 17, 0, 13, 13, 0, 13, 18, 0, 14, 24, 0, 11, 5, 0, 15, 23, 0, 7, 7, 0, 11, 26, 0, 14, 12, 0, 14, 19, 0, 16, 21, 255, 9, 5, 0, 7, 24, 0, 16, 10, 255, 9, 26, 0, 10, 5, 0, 10, 26, 0, 15, 11, 0, 15, 20, 0, 7, 8, 255, 7, 23, 255, 7, 24, 255, 12, 6, 0, 12, 13, 0, 12, 18, 0, 12, 25, 0, 16, 22, 255, 7, 7, 255, 11, 6, 0, 11, 25, 0, 13, 7, 0, 7, 9, 255, 7, 22, 255, 8, 6, 0, 8, 25, 0, 11, 13, 0, 13, 24, 0, 7, 11, 255, 7, 20, 255, 9, 6, 0, 10, 6, 0, 10, 25, 0, 11, 18, 0, 7, 11, 0, 7, 20, 0, 9, 6, 255, 10, 25, 255, 11, 13, 255, 7, 9, 0, 7, 22, 0, 10, 6, 255, 11, 18, 255, 8, 6, 255, 8, 25, 255, 11, 6, 255, 11, 25, 255, 13, 7, 255, 13, 24, 255, 7, 7, 0, 7, 24, 0, 12, 13, 255, 12, 18, 255, 7, 8, 0, 7, 23, 0, 12, 6, 255, 12, 25, 255, 16, 22, 0, 10, 26, 255, 15, 11, 255, 15, 20, 255, 9, 5, 255, 9, 26, 255, 10, 5, 255, 16, 10, 0, 7, 7, 255, 7, 24, 255, 11, 5, 255, 11, 26, 255, 14, 12, 255, 14, 19, 255, 16, 21, 0, 13, 18, 255, 14, 24, 255, 15, 23, 255, 10, 14, 255, 10, 17, 255, 11, 14, 255, 11, 17, 255, 13, 13, 255, 13, 25, 255, 14, 7, 255, 10, 14, 0, 10, 17, 0, 11, 14, 0, 11, 17, 0, 13, 13, 0, 13, 18, 0, 13, 25, 0, 14, 7, 0, 7, 7, 0, 7, 24, 0, 11, 5, 0, 11, 26, 0, 14, 12, 0, 14, 19, 0, 14, 24, 0, 15, 23, 0, 16, 21, 255, 9, 5, 0, 9, 26, 0, 10, 5, 0, 10, 26, 0, 15, 11, 0, 15, 20, 0, 16, 10, 255, 7, 8, 255, 7, 23, 255, 7, 24, 255, 12, 6, 0, 12, 13, 0, 12, 18, 0, 12, 25, 0, 16, 22, 255, 7, 7, 255, 8, 6, 0, 11, 6, 0, 11, 25, 0, 13, 7, 0, 13, 24, 0, 7, 9, 255, 7, 11, 255, 7, 20, 255, 7, 22, 255, 8, 25, 0, 9, 6, 0, 10, 6, 0, 10, 25, 0, 11, 13, 0, 11, 18, 0, 9, 25, 0, 16, 9, 255, 9, 6, 255, 9, 25, 255, 10, 25, 255, 11, 13, 255, 11, 18, 255, 15, 11, 255, 15, 20, 255, 7, 9, 0, 7, 11, 0, 7, 20, 0, 7, 22, 0, 8, 6, 255, 8, 25, 255, 10, 6, 255, 11, 6, 255, 11, 25, 255, 12, 13, 255, 12, 18, 255, 13, 7, 255, 13, 24, 255, 14, 7, 255, 14, 12, 255, 14, 19, 255, 14, 24, 255, 15, 8, 255, 15, 23, 255, 7, 11, 255, 7, 12, 255, 7, 19, 255, 7, 20, 255, 8, 13, 255, 8, 18, 255, 12, 6, 255, 12, 25, 255, 13, 6, 255, 13, 13, 255, 13, 18, 255, 13, 25, 255, 15, 7, 255, 15, 12, 255, 15, 19, 255, 15, 24, 255, 7, 6, 255, 7, 9, 255, 7, 10, 255, 7, 13, 255, 7, 18, 255, 7, 21, 255, 7, 22, 255, 7, 25, 255, 9, 26, 255, 10, 5, 255, 10, 26, 255, 11, 5, 255, 11, 14, 255, 11, 26, 255, 14, 6, 255, 14, 13, 255, 14, 18, 255, 14, 25, 255, 15, 6, 255, 15, 13, 255, 15, 18, 255, 15, 25, 255, 16, 11, 255, 16, 20, 255, 16, 23, 255, 7, 5, 255, 7, 26, 255, 8, 5, 255, 8, 14, 255, 8, 17, 255, 8, 26, 255, 9, 5, 255, 9, 14, 255, 9, 17, 255, 10, 14, 255, 10, 17, 255, 11, 17, 255, 12, 5, 255, 12, 14, 255, 12, 17, 255, 12, 26, 255, 13, 5, 255, 13, 14, 255, 13, 17, 255, 13, 26, 255, 14, 5, 255, 14, 14, 255, 14, 17, 255, 14, 26, 255, 16, 8, 255, 16, 24, 255, 6, 6, 255, 6, 7, 255, 6, 8, 255, 6, 9, 255, 6, 10, 255, 6, 11, 255, 6, 12, 255, 6, 19, 255, 6, 20, 255, 6, 21, 255, 6, 22, 255, 6, 23, 255, 6, 24, 255, 6, 25, 255, 7, 14, 255, 7, 17, 255, 15, 5, 255, 15, 14, 255, 15, 17, 255, 15, 26, 255, 16, 7, 255, 16, 12, 255, 16, 19, 255, 6, 18, 255, 6, 18, 0, 16, 7, 0, 16, 8, 0, 16, 9, 0, 16, 10, 0, 16, 11, 0, 16, 12, 0, 16, 19, 0, 16, 20, 0, 16, 21, 0, 16, 22, 0, 6, 6, 0, 6, 7, 0, 6, 8, 0, 6, 9, 0, 6, 10, 0, 6, 11, 0, 6, 12, 0, 6, 19, 0, 6, 20, 0, 6, 21, 0, 6, 22, 0, 6, 23, 0, 6, 24, 0, 6, 25, 0, 7, 14, 0, 7, 17, 0, 15, 5, 0, 15, 14, 0, 15, 17, 0, 15, 26, 0, 16, 23, 0, 16, 24, 0, 7, 5, 0, 7, 26, 0, 8, 14, 0, 8, 17, 0, 14, 5, 0, 14, 14, 0, 14, 17, 0, 14, 26, 0, 8, 5, 0, 8, 26, 0, 9, 5, 0, 9, 14, 0, 9, 17, 0, 9, 26, 0, 10, 5, 0, 10, 14, 0, 10, 17, 0, 11, 5, 0, 12, 5, 0, 12, 14, 0, 12, 26, 0, 13, 5, 0, 13, 14, 0, 13, 17, 0, 13, 26, 0, 10, 26, 0, 11, 14, 0, 11, 17, 0, 11, 26, 0, 12, 17, 0, 7, 6, 0, 15, 6, 0, 15, 25, 0, 7, 13, 0, 7, 18, 0, 7, 25, 0, 15, 13, 0, 15, 18, 0, 0, 0, 0, 0, 0, 0, 0, 0, 0, 0, 0, 0, 0, 0, 0, 0, 0, 0, 0, 0, 0, 0, 0, 0, 0, 0, 0, 0, 0, 0, 0, 0, 0, 0, 0, 0, 0, 0, 0, 0, 0, 0, 0, 0, 0, 0, 0, 0, 0, 0, 0, 0, 0, 0, 0, 0, 0, 0, 0, 0, 0, 0, 0, 0, 0, 0, 0, 0, 0, 0, 0, 0, 0, 0, 0, 0, 0, 0, 0, 0, 0, 0, 0, 0, 0, 0, 0, 0, 0, 0, 0, 0, 0, 0, 0, 0, 0, 0, 0, 0, 0, 0, 0, 0, 0, 0, 0, 0, 0, 0, 0, 0, 0, 0, 0, 0, 0, 0, 0, 0, 0, 0, 0, 0, 0, 0, 0, 0, 0, 0, 0, 0, 0, 0, 0, 0, 0, 0, 0, 0, 0, 0, 0, 0, 0, 0, 0, 0, 0, 0, 0, 0, 0, 0, 0, 0, 0, 0, 0, 0, 0, 0, 0, 0, 0, 0, 0, 0, 0, 0, 0, 0, 0, 0, 0, 0, 0, 0, 0, 0, 0, 0, 0, 0, 0, 0, 0, 0, 0, 0, 0, 0, 0, 0, 0, 0, 0, 0, 0, 0, 0, 0, 0, 0, 0, 0, 0, 0, 0, 0, 0, 0, 0, 0, 0, 0, 0, 0, 0, 0, 0, 0, 0, 0, 0, 0, 0, 0, 0, 0, 0, 0, 0, 0, 0, 0, 0, 0, 0, 0, 0, 0, 0, 0, 0, 0, 0, 0, 0, 0, 0, 0, 0, 0, 0, 0, 0, 0, 0, 0, 0, 0, 0, 0, 0, 0, 0, 0, 0, 0, 0, 0, 0, 0, 0, 0, 0, 0, 0, 0, 0, 0, 0, 0, 0, 0, 0, 0, 0, 0, 0, 0, 0, 0, 0, 0, 0, 0, 0, 0};
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
void loop() {
  Serial.println(freeMemory());
  unsigned char animacion_nueva = read_input();
  if (animacion_actual !=  animacion_nueva) {
    load_new_animation(lista_animaciones[animacion_nueva]);
    animacion_actual = animacion_nueva;
  }else {
    // Renderizamos los frames
    if (actual_frame == n_frames) {
      actual_frame = 0;
      last = 1 + n_frames;
      //load_new_animation(lista_animaciones[0]);
      //animacion_actual = 0;
    }
  
    for (int j = 0; j < lista_cambios[actual_frame]; j++) {
   unsigned char color = pgm_read_byte_near(animacion + last + 2);
   myGLCD.setColor(color, color, color);
   myGLCD.fillRoundRect(pgm_read_byte_near(animacion + last + 1) * 10,
     pgm_read_byte_near(animacion + last) * 10,
     pgm_read_byte_near(animacion + last + 1) * 10 + 10,
     pgm_read_byte_near(animacion + last) * 10 + 10);
   last += 3;
  }
  actual_frame++;
  
  delay(20);
  }
  
  
}

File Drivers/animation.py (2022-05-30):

import RPi.GPIO as GPIO
import time

pin1, pin2, pin3 = 32, 38, 40

GPIO.setmode(GPIO.BOARD)
GPIO.setup(pin1, GPIO.OUT)
GPIO.setup(pin2, GPIO.OUT)
GPIO.setup(pin3, GPIO.OUT)

def animation0():
    GPIO.output(pin1, GPIO.LOW)
    GPIO.output(pin2, GPIO.LOW)
    GPIO.output(pin3, GPIO.LOW)

def animation1():
    GPIO.output(pin1, GPIO.HIGH)
    GPIO.output(pin2, GPIO.LOW)
    GPIO.output(pin3, GPIO.LOW)

def animation2():
    GPIO.output(pin1, GPIO.LOW)
    GPIO.output(pin2, GPIO.HIGH)
    GPIO.output(pin3, GPIO.LOW)

def animation3():
    GPIO.output(pin1, GPIO.HIGH)
    GPIO.output(pin2, GPIO.HIGH)
    GPIO.output(pin3, GPIO.LOW)

def animation4():
    GPIO.output(pin1, GPIO.LOW)
    GPIO.output(pin2, GPIO.LOW)
    GPIO.output(pin3, GPIO.HIGH)

def animation5():
    GPIO.output(pin1, GPIO.HIGH)
    GPIO.output(pin2, GPIO.LOW)
    GPIO.output(pin3, GPIO.HIGH)

def animation6():
    GPIO.output(pin1, GPIO.LOW)
    GPIO.output(pin2, GPIO.HIGH)
    GPIO.output(pin3, GPIO.HIGH)

while True:
    animation0()
    time.sleep(6)
    animation1()
    time.sleep(6)
    animation2()
    time.sleep(6)
    animation3()
    time.sleep(6)
    animation4()
    time.sleep(6)
    animation5()
    time.sleep(6)
    animation6()
    time.sleep(6)

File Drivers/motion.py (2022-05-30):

from adafruit_servokit import ServoKit
import RPi.GPIO as GPIO
import time

myKit = ServoKit(channels=16)

# BRAZOS
pinA, pinB = 7, 12

GPIO.setmode(GPIO.BOARD)
GPIO.setup(pinA, GPIO.OUT)
GPIO.setup(pinB, GPIO.OUT)

def state0():
    GPIO.output(pinA, GPIO.LOW)
    GPIO.output(pinB, GPIO.LOW)

def state1():
    GPIO.output(pinA, GPIO.HIGH)
    GPIO.output(pinB, GPIO.LOW)

def state2():
    GPIO.output(pinA, GPIO.LOW)
    GPIO.output(pinB, GPIO.HIGH)

def state3():
    GPIO.output(pinA, GPIO.HIGH)
    GPIO.output(pinB, GPIO.HIGH)

# MOTORES DC

A1A = 35
A1B = 36

A2A = 37
A2B = 38

GPIO.setmode(GPIO.BOARD)
GPIO.setup(A1A, GPIO.OUT)
GPIO.setup(A1B, GPIO.OUT)
GPIO.setup(A2A, GPIO.OUT)
GPIO.setup(A2B, GPIO.OUT)

def parar():
    GPIO.output(A1A, GPIO.LOW)
    GPIO.output(A1B, GPIO.LOW)

    GPIO.output(A2A, GPIO.LOW)
    GPIO.output(A2B, GPIO.LOW)

def go():
    GPIO.output(A1A, GPIO.LOW)
    GPIO.output(A1B, GPIO.HIGH)

    GPIO.output(A2A, GPIO.LOW)
    GPIO.output(A2B, GPIO.HIGH)

def back():
    GPIO.output(A1A, GPIO.HIGH)
    GPIO.output(A1B, GPIO.LOW)
	
    GPIO.output(A2A, GPIO.HIGH)
    GPIO.output(A2B, GPIO.LOW)

def girar_derecha():
    GPIO.output(A1A, GPIO.HIGH)
    GPIO.output(A1B, GPIO.LOW)
	
    GPIO.output(A2A, GPIO.LOW)
    GPIO.output(A2B, GPIO.HIGH)

def girar_izquierda():
    GPIO.output(A1A, GPIO.LOW)
    GPIO.output(A1B, GPIO.HIGH)
	
    GPIO.output(A2A, GPIO.HIGH)
    GPIO.output(A2B, GPIO.LOW)

# SENSORES CAIDA
sensor_left = 13
sensor_right = 15

GPIO.setmode(GPIO.BOARD)
GPIO.setup(sensor_left, GPIO.IN)
GPIO.setup(sensor_right, GPIO.IN)

def detectar_caida():
    detect_object_left = GPIO.input(sensor_left)
    detect_object_right = GPIO.input(sensor_right)

    return detect_object_left or detect_object_right

# ANIMACIONES

pin1, pin2, pin3 = 32, 38, 40

GPIO.setmode(GPIO.BOARD)
GPIO.setup(pin1, GPIO.OUT)
GPIO.setup(pin2, GPIO.OUT)
GPIO.setup(pin3, GPIO.OUT)

def animation0():
    GPIO.output(pin1, GPIO.LOW)
    GPIO.output(pin2, GPIO.LOW)
    GPIO.output(pin3, GPIO.LOW)

def animation1():
    GPIO.output(pin1, GPIO.HIGH)
    GPIO.output(pin2, GPIO.LOW)
    GPIO.output(pin3, GPIO.LOW)

def animation2():
    GPIO.output(pin1, GPIO.LOW)
    GPIO.output(pin2, GPIO.HIGH)
    GPIO.output(pin3, GPIO.LOW)

def animation3():
    GPIO.output(pin1, GPIO.HIGH)
    GPIO.output(pin2, GPIO.HIGH)
    GPIO.output(pin3, GPIO.LOW)

def animation4():
    GPIO.output(pin1, GPIO.LOW)
    GPIO.output(pin2, GPIO.LOW)
    GPIO.output(pin3, GPIO.HIGH)

def animation5():
    GPIO.output(pin1, GPIO.HIGH)
    GPIO.output(pin2, GPIO.LOW)
    GPIO.output(pin3, GPIO.HIGH)

def animation6():
    GPIO.output(pin1, GPIO.LOW)
    GPIO.output(pin2, GPIO.HIGH)
    GPIO.output(pin3, GPIO.HIGH)

# SENSOR FRONTAL
frontal_sensor = 16

GPIO.setmode(GPIO.BOARD)
GPIO.setup(frontal_sensor,GPIO.IN)
def detector_frontal():
    detect_object = GPIO.input(frontal_sensor)
    return detect_object

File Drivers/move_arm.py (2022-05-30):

from adafruit_servokit import ServoKit
import time

myKit = ServoKit(channels=16)
while True:
    myKit.servo[1].angle = 90
    myKit.servo[2].angle = 0
    time.sleep(1)
    myKit.servo[1].angle = 0
    myKit.servo[2].angle = 90
    time.sleep(1)

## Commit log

2022-04-20 Adding hardware and sprint part to project
    [electronic_design.fzz]
2022-04-20 Adding models for printing and report of sprint 1
    [brazos.stl, cuerpo1.stl, cuerpo2.stl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]
2022-04-27 Updating hardware scheme
    [electronic_design.fzz]
2022-05-08 Empezando a usar la maquina de estados, multiprocessing funciona bien!!
2022-05-25 Otra victoria mas para el equipo de software
2022-05-26 Adding move arm code
2022-05-27 Update hardwaredesign
    [electronic_design.fzz]
2022-05-29 Otro exito mas para el equipo de software
2022-05-29 Update drivers
2022-05-30 Más victorias que Ferndo Alonso
2022-05-30 Ahora funciona el audio
    [README.configure.txt]
